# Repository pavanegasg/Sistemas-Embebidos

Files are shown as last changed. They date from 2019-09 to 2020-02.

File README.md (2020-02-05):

# EmPet
```
Maria Elisa Castro Fuñez 
Gabriel Martinez
Julian Molina 
Nicold Peña 
Juan Camilo Ramirez
Oscar Mauricio Segura 
Pedro Alejandro Vanegas 
```

### [Test de los 6 sombreros](https://github.com/pavanegasg/Sistemas-Embebidos/tree/master/Documentos/Test%20de%20los%206%20sombreros)

### Encontrando relaciones - escaleras preguntas

<p align="center">
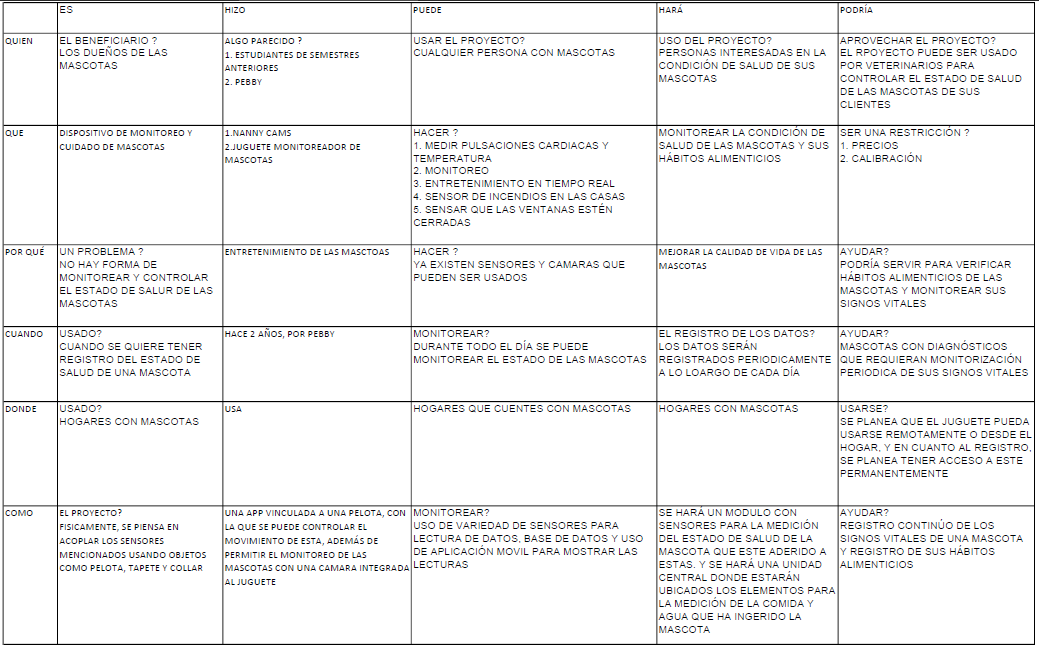
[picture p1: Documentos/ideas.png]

</p>

### Diagramas 

<p align="center">
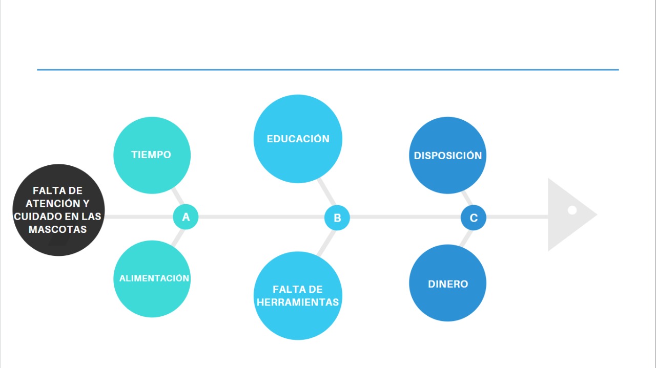
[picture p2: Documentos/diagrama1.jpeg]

</p>

<p align="center">
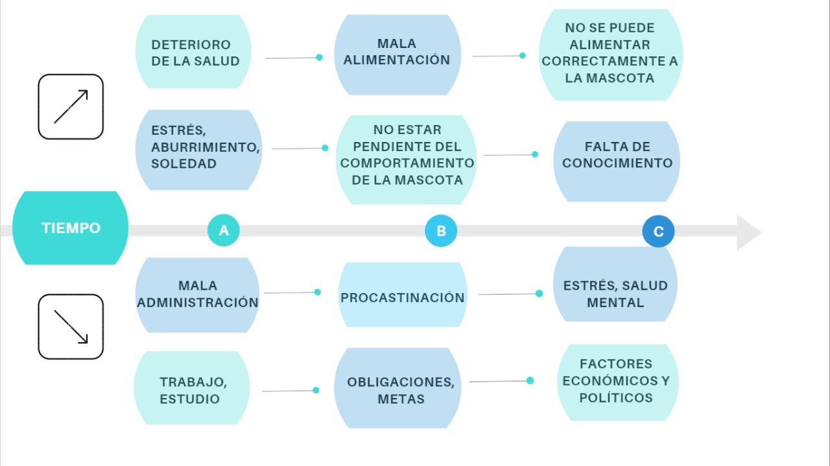
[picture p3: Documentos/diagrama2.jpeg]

</p>

### Problema 

<p align="center">
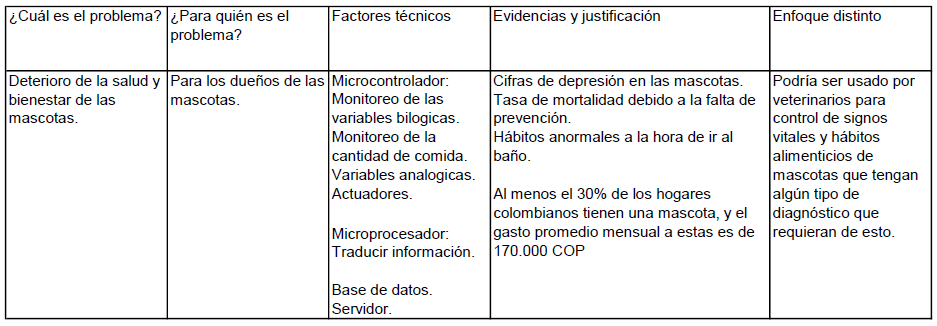
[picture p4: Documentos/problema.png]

</p>

### Asignación de tareas 

<p align="center">
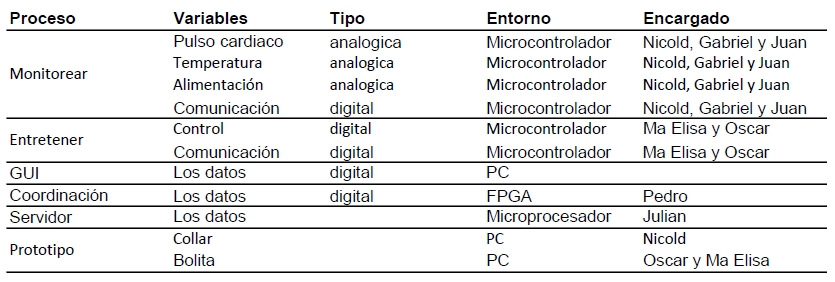
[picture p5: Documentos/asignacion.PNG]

</p>

### [Anteproyecto](https://github.com/pavanegasg/Sistemas-Embebidos/blob/master/Documentos/Anteproyecto_embebidos.pdf) 

### [Manuales](https://github.com/pavanegasg/Sistemas-Embebidos/tree/master/Manuales)

### [Códigos](https://github.com/pavanegasg/Sistemas-Embebidos/tree/master/Códigos)

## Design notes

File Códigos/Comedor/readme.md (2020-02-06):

**Nota:** Para la implementación de este codigo se hace necesario realizar una conexión por medio de UART con la FPGA, codigo desarrollado en la respectiva carpeta de dicha tarjeta.

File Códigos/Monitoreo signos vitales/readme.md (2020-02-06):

**Nota:** Este esta compuesto por dos códigos, uno para Arduino y uno para el modulo NodeMCU, los cuales trabajan en conjunto para enviar la información al servidor en la Raspberry.

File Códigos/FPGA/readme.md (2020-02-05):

El uso de la FPGA fue la conexión entre las [celdas de carga](https://github.com/pavanegasg/Sistemas-Embebidos/tree/master/Documentaci%C3%B3n/Sensores/HX711%20y%20celda%20de%20carga) y el [microprocesador](https://github.com/pavanegasg/Sistemas-Embebidos/tree/master/Manuales/Raspberry), además del procesamiento de la señal recibida del alimento y el agua de la mascota.

### 1. Conexión Microcontrolador-FPGA:

Esta conexión permite obtener los datos provenientes de las celdas de carga y llevarlos a la FPGA. La comunicación se hace en paralelo, donde se envían 8 bits correspondientes a cada dato, 16 en total para agua y comida.
   * Primera prueba:
   La primera prueba fue recibir datos de 4 bits para enviar esos mismos datos como salida y mostrar ese valor en los leds.
   
```verilog 
// rece.v

module rece( 
	input clk,                // Declaración de variables
	input [3:0] entero,
	output [3:0] tes,
	output [3:0] leds
	);

	assign leds[3] = RD ? !entero[3] : 1'b1;      //Asignación de leds
	assign leds[2] = RD ? !entero[2] : 1'b1;
	assign leds[1] = RD ? !entero[1] : 1'b1;
	assign leds[0] = RD ? !entero[0] : 1'b1;

	assign tes[3] = RD ? entero[3] : 1'b0;        //Asignación de salida 
	assign tes[2] = RD ? entero[2] : 1'b0;
	assign tes[1] = RD ? entero[1] : 1'b0;
	assign tes[0] = RD ? entero[0] : 1'b0;

	reg RD = 1;
	reg [1:0] state = START;
	parameter START=0, S1=1, STOP=2;

	reg divisor = 0;
	wire div;
	
	divisor divI(
		.clk(clk),
		.inicio(divisor),
		.CLKOUT(div)
		);

always @ (posedge clk)        //Máquina de estados para reiniciar el valor de la salida 
begin				
	case (state)
		
		START: begin	
			RD <= 1;
			state <= STOP;
		end

		STOP: begin 
			divisor <= 1;
			if(div) begin
			divisor <= 0; 
			RD <= 0;
			state <= START;
			end 
		end
	endcase
end 

endmodule   
```   
   * Segunda prueba:
     El segundo diseño consitió en recibir un número de 4 bits, y hacer que la salida fuera ese número menos el número recibido inmediatamente anterior. Adicionalmente, se muestra el valor de la salida en los leds de la tarjeta.
     
 ```verilog
 // ardn.v
 
 module rece( 
	input clk,
	input [3:0] dato,         //Definición de variables 
	output [3:0] salida,
	output [3:0] leds
	);

	assign salida = val;            // Asignación a la salida 
  reg [3:0] val;  
	assign leds = !salida;          // Asignación a los leds

	reg [1:0] state = START;
	parameter START=0, S1=1, STOP=2;

	reg divisor = 0;
	reg [3:0] valAnt = 0;
	wire div;
	
	divisor divI(           // Divisor para enviar el dato cada que se quiera
		.clk(clk),
		.inicio(divisor),
		.CLKOUT(div)
		);

always @ (posedge clk)     // Máquina de estados para almacenar valor anterior 
  begin				
	  case (state)
		
		START: begin	
			state <= STOP;
			valAnt <= dato;
      val <= 0;
		end

		STOP: begin           // Espera para enviar el siguiente dato
			divisor <= 1;
			if(div) begin
			divisor <= 0; 
			state <= START;
      val <= valAnt-dato;
			end 
		end

		default:
			state <= START;

	endcase
end 

endmodule    
```

### 2. Conexión FPGA-Microcontrolador
  
  La segunda parte consiste en enviar datos al microcontrolador por comunicación serial, para este caso se escogió UART, dada la fácil implementación. Los datos a enviar son los referentes a la diferencia de comida y agua actual con la medida un instante antes. 
  
  * Primera prueba:
 La primera prueba para esta sección fue la implementación de un puerto UART desde la FPGA, ya que a pesar de que la BlackIceMX cuenta con puertos seriales estos no están conectados directamente a la FPGA. El puerto implementado es una adaptación del puerto disponible en [open-fpga-verilog-tutorial](https://github.com/Obijuan/open-fpga-verilog-tutorial/wiki)

```verilog
//uart_tx.v

`default_nettype none
`include "baudgen.vh"

module uart_tx 
    #(
    parameter BAUD = `B115200
    )
    (
         input wire clk,        //-- Reloj del sistema (25MHz BlackIceMx)
         input wire rstn,       //-- Reset global
         input wire start,      //-- Activar a 1 para transmitir
         input wire [7:0] data, //-- Byte a transmitir
         output reg tx,         //-- Salida de datos serie
         output wire ready      //-- Transmisor listo / ocupado
       );

reg start_r; 
wire clk_baud;

//-- Bitcounter
reg [3:0] bitc;

//-- Datos registrados
reg [7:0] data_r;

//--------- Microordenes
wire load;    //-- Carga del registro de desplazamiento. Puesta a 0 del
              //-- contador de bits
wire baud_en; //-- Habilitar el generador de baudios para la transmision

//-------------------------------------
//-- RUTA DE DATOS
//-------------------------------------

//-- Registrar la entrada start

always @(posedge clk)
  start_r <= start;

always @(posedge clk)
  if (start == 1 && state == IDLE)
    data_r <= data;

//-- Registro de 10 bits para almacenar la trama a enviar:
//-- 1 bit start + 8 bits datos + 1 bit stop
reg [9:0] shifter;

//-- Cuando la microorden load es 1 se carga la trama
//-- con load 0 se desplaza a la derecha y se envia un bit, al
//-- activarse la señal de clk_baud que marca el tiempo de bit
//-- Se introducen 1s por la izquierda

always @(posedge clk)
  //-- Reset
  if (rstn == 0)
    shifter <= 10'b11_1111_1111;

  //-- Modo carga
  else if (load == 1)
    shifter <= {data_r,2'b01};

  //-- Modo desplazamiento
  else if (load == 0 && clk_baud == 1)
    shifter <= {1'b1, shifter[9:1]};

//-- Contador de bits enviados
//-- Con la microorden load (=1) se hace un reset del contador
//-- con load = 0 se realiza la cuenta de los bits, al activarse
//-- clk_baud, que indica el tiempo de bit

always @(posedge clk)
  if (load == 1)
    bitc <= 0;
  else if (load == 0 && clk_baud == 1)
    bitc <= bitc + 1;

//-- Sacar por tx el bit menos significativo del registros de desplazamiento
//-- ES UNA SALIDA REGISTRADA, puesto que tx se conecta a un bus sincrono
//-- y hay que evitar que salgan pulsos espureos (glitches)

always @(posedge clk)
  tx <= shifter[0];

//-- Divisor para obtener el reloj de transmision
baudgen #(.BAUD(BAUD))
  BAUD0 (
    .clk(clk),
    .clk_ena(baud_en),
    .clk_out(clk_baud)
  );

//------------------------------
//-- CONTROLADOR
//------------------------------

//-- Estados del automata finito del controlador
localparam IDLE  = 0;  //-- Estado de reposo
localparam START = 1;  //-- Comienzo de transmision
localparam TRANS = 2;  //-- Estado: transmitiendo dato

//-- Estados del autómata del controlador
reg [1:0] state;

//-- Transiciones entre los estados
always @(posedge clk)

  //-- Reset del automata. Al estado inicial
  if (rstn == 0)
    state <= IDLE;

  else
    //-- Transiciones a los siguientes estados
    case (state)

      //-- Estado de reposo. Se sale cuando la señal
      //-- de start se pone a 1
      IDLE: 
        if (start_r == 1) 
          state <= START;
        else 
          state <= IDLE;

      //-- Estado de comienzo. Prepararse para empezar
      //-- a transmitir. Duracion: 1 ciclo de reloj
      START:
        state <= TRANS;

      //-- Transmitiendo. Se esta en este estado hasta
      //-- que se hayan transmitido todos los bits pendientes
      TRANS:
        if (bitc == 11)
          state <= IDLE;
        else
          state <= TRANS;

      //-- Por defecto. NO USADO. Puesto para
      //-- cubrir todos los casos y que no se generen latches
      default:
        state <= IDLE;

    endcase

//-- Generacion de las microordenes
assign load = (state == START) ? 1 : 0;
assign baud_en = (state == IDLE) ? 0 : 1;

//-- Señal de salida. Esta a 1 cuando estamos en reposo (listos
//-- para transmitir). En caso contrario esta a 0
assign ready = (state == IDLE) ? 1 : 0;

endmodule
```

* Segunda prueba
  * Primera parte:
  La segunda prueba fue incorporar los datos provenientes de las celdas de carga y el modulo `uart_tx.v`. Primero se utilizó un valor fijo para la lectura de comida y agua.
  
```verilog  
//Top.v

`include "baudgen.vh"

	module Top(					// Declaración de variables
			input clk,			//	
			input [3:0] datoAgua,		
			input [3:0] datoPeso,
			output wire tx,
			output [1:0] stat
			);

	//Cables y registros para conexión de modulos 

	parameter BAUD = `B115200;			// Definición de tasa de baudios a usar en la comunicación serial

		reg resetUart = 0;			// Cables y registros para conexión de modulos
		reg startUart;

		wire [3:0] Comida;
		wire [3:0] Agua;

		wire [7:0] comidaFinal;
		wire [7:0] aguaFinal;
		assign comidaFinal = 8'b01111011;	// Valor fijo de agua y comida
		assign aguaFinal = 8'b01111101;
		reg [7:0] data;

		reg counter;				// Contador para máquina de estado	
		reg cena;
		wire readyUart;

		reg divStart = 0;
		wire divOut;

	//Instanciación modulos

	always @(posedge clk) begin			// Inicialización puerto serial 
		resetUart <= 1;
	end

	uart_tx #(.BAUD(BAUD)) Uart_txComida(		// Instanciación de modulos
			.clk(clk),
			.rstn(resetUart),
			.start(startUart),
			.data(data),
			.tx(tx),
			.ready(readyUart)
			);

	aguaMedida medicionAgua(
			.clk(clk),
			.agua(datoAgua),
			.salidaAgua(Agua)
			);

	pesoMedida medicionComida(
			.clk(clk),
			.peso(datoPeso),
			.salidaPeso(Comida)
			);

	always @*					// Contador
  		case (counter)
    		1'b0: data <= comidaFinal;
   			1'b1: data <= aguaFinal;
    		default: data <= ".";
  		endcase

  	always @(posedge clk)
		if (resetUart == 0)
    		counter = 0;
  		else if (cena)
    		counter = counter + 1;

	divisorTop divider(
		.clk(clk),
		.inicio(divStart),
		.CLKOUT(divOut)
		);

	// Máquina de estados para el control de las señales

	reg [1:0] state = START;
	parameter START=0, S1=1, S2=2, WAIT=3;
	assign stat = state;

	always @ (posedge clk)
	begin

		case(state)
			
			START: begin 				// Espera inicial
				divStart <= 1;
				if(divOut) begin 
					state <= S1;
					divStart <= 0;
				end
				else state <= START;
			end
		
			S1:  begin				// Transmisión de comida y agua 
				if(readyUart == 1) state <= S2;
				else state <= S1;
			end

			S2: begin				// Regresar a estado anterior cuando ya se haya transmitido 
				if(counter == 1) state <= WAIT; // comida. Pasar a estado siguiente cuando se hayan 
				else state <= S1;		// transmitido los dos valores
			end

			WAIT: begin				// Espera de 10 segundos
				divStart <= 1;
				if(divOut) begin 
					state <= START;
					divStart <= 0;
				end
				else state <= WAIT;
			end

			default: state <= START;

		endcase

	end

	always @*						// Asignación de microordenes

			case(state)
				START: begin
					startUart <= 0;
					cena <= 0;
				end

				S1: begin
					startUart <= 1;
					cena <= 0;
				end

				S2: begin  
					startUart <= 0;
					cena <= 1;
				end

				WAIT: begin
					startUart <= 0;
					cena <= 0;
				end

				default: begin 
					startUart <= 0;
					cena <= 0;
				end

			endcase

endmodule

```  

  * Segunda parte:
  La parte final fue cambiar el valor fijo de agua y comida y probar la transmisión.

 ### NOTA: Las versiones finales de los archivos y modulos mencionados están disponibles.

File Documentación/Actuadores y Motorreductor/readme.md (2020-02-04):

## Motorreductor
Un motorreductor es un reductor de velocidad con un motor directamente conectado. Entre sus ventajas se encuentra la compatibilidad con microcontroladores, Arduino, puede emplearse un cambio de velocidad con señales PWM y poseen un diseño compacto. Para esta apliacción se hizo uso de un motorreductor de 100rpm a 6V.

<p align="center">
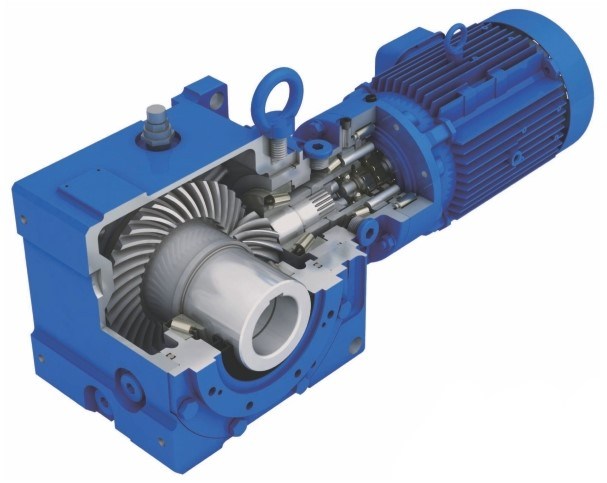
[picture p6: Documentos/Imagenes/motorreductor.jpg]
  
</p>

## Driver L298D
Un motor DC cambia el sentido de giro cuado invertimos los polos positivo y negativo en sus bordes,con ayuda del driver podemos realizar ese cambio de polaridad. El Driver puente H para motores L293D es un circuito integrado de cuatro canales diseñado para manejar cargas inductivas tal como lo es un motores DC hasta con una salida máxima de corriente de 600mA por canal en la configuración conocida como puente H. 

<p align="center">
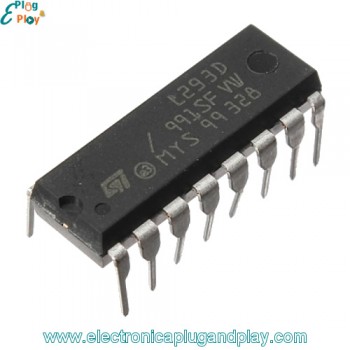
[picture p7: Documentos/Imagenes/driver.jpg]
  
</p>

## Señales PWM
El arduino puede generar señales PWM y así simular una tensión menor en voltios. Estas señales son las que permiten controlar el motor a través del puente H y controlar así la velocidad

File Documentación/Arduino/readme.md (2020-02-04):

## ¿Que es Arduino?

Esta es una compañía, proyecto y comunidad de hardware y software open-source que diseña y fabrica placas cuyo núcleo son microcontroladores, sus productos están licenciados bajo la LGPL o la GPL, lo cual permite la manufactura de placas Arduino por cualquier persona o entidad.
Esta es  ampliamente utilizada debido a su facilidad para la programación y la gran cantidad de librerías y sensores compatibles con esta, comercialmente hay gran variedad de placas Arduino, entre las que se destacaran el Arduino Nano y el Arduino Mega, las cuales serán empleadas en la realización de este proyecto.

## Prerrequisitos.

Para la utilización de estas placas hay gran variedad de programas mediante los cuales estas pueden ser programadas, entre ellas se destacan Visual Studio Code empleando la librería especifica para Arduino, Arduino Pro IDE (aun en beta) y Arduino IDE. Para la realización de este proyecto se empleo Arduino IDE, la cual puede ser descargada de manera gratuita en la pagina oficial de Arduino.

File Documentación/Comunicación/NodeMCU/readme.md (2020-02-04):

## ¿Qué es NodeMCU?
El NodeMCU es una plataforma IoT de código abierto basado en el chip ESP8266 (ESP-12E), siendo un entorno propicio para aplicaciones que requieran conectividad WiFi, de manera que es posible enviar y recibir datos e incluso controlas pines de entrada y salida de forma remota, de esta misma manera también es posible por medio de comunicación serial obtener los datos de los sensores recopilados por el arduino.

<p align="center">
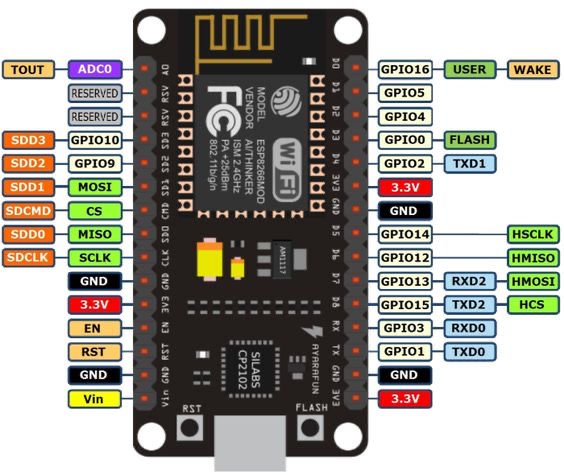
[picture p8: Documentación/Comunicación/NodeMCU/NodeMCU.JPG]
  
</p>

## Específicaciones técnicas

    -Procesador: ESP8266 @ 80MHz (3.3V) (ESP-12E)
    -4MB de memoria FLASH (32 MBit)
    -WiFi 802.11 b/g/n
    -Regulador 3.3V integrado (500mA)
    -Conversor USB-Serial CH340G / CH340G
    -Función Auto-reset 
    -9 pines GPIO con I2C y SPI
    -1 entrada analógica (1.0V max)
    -4 agujeros de montaje (3mm)
    -Pulsador de RESET
    -Entrada alimentación externa VIN (20V max)

## Prerrequisitos
Para realizar la respectiva utilización de este modulo, especialmente si se quiere utilizar un entorno conocido de programación se hace necesario instalar el pluggin del ESP8266 en el IDE de Arduino con el fin de evitar montar un entorno de desarrollo para utilizar la SDK de Espressif y posteriormente de la misma forma en que se procede en Arduino instalar la libreria PubSubClient, con el fin de convertir dicho módulo en el cliente del servidor ubicado en la Raspberry Pi.

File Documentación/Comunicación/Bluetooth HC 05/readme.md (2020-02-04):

## Bluetooth HC 05
El módulo Bluetooth HC-05 permite conectar el proyecto con Arduino nano a un celular de manera inalámbrica (Bluetooth). La comunicación
Bluetooth se da entre dos tipos de dispositivos: Maestro y Esclavo.  El módulo Bluetooth HC-05 viene configurado de fábrica para trabajar 
como esclavo, es decir, preparado para escuchar peticiones de conexión; lo cual es conveniente en este caso ya que el celular se comportará
como maestro.

 <p align="center">
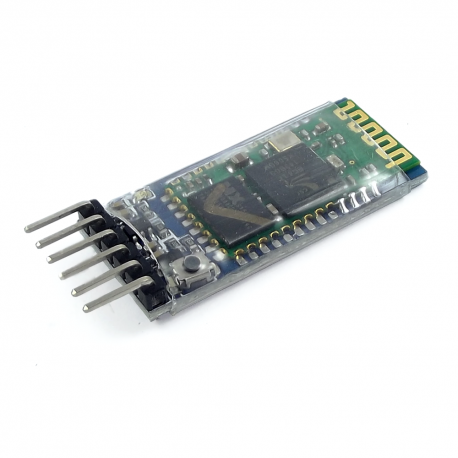
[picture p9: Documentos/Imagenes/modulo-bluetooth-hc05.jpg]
hover text
  
</p>
Este módulo cumple con las especificaciones del estándar Bluetooth 2.0 que es perfectamente compatible con celulares o smartphones Android, 
más no con los Iphone. 

## Especificaciones Técnicas

     -Voltaje de operación: 3.6V - 6V DC
     -Consumo corriente: 50mA
     -Alcance 10 metros
     -Interface comunicación: Serial TTL
     -Baudrate por defecto: 9600.
     -Temperatura de trabajo: -20C a +75C
     -Compatible con Android

## Estados del módulo 

 **Estado conectado**
 
 - Entra a este estado una vez se ha alimentao el módulo no se ha establecido una conexión bluetooth con ningún otro dispositivo.
 - EL LED del módulo en este estado parpadea rápidamente
 
 **Estado desconectado**
 
 - Entra a este estado cuando se establece una conexión con otro dispositivo bluetooth.
 - El LED hace un doble parpadeo.
 
 ## Conexión con el celular
 
El celular como se había mencionado anteriormente, funciona en este caso como maestro. La conexión se realiza mediante la app creada con el SDK de código abierto, Ionic. La cual posee un complemente llamado **Bluetooth Serial**, facilitando la comunicación. 

    //Instalación del complemento
    $ ionic cordova plugin add cordova-plugin-bluetooth-serial
    $ npm install --save @ionic-native/bluetooth-serial

Posteriormente se definen en el archivo **.ts** las funciones que por medio de la dirección permiten realizar la conexión entre la app y el dispositivo (HC 05). 
  
    -CheckBluetoothEnable()
    -ListPairedDevices()
    -SelectDevice()
    -connect(address)
    -deviceConnect()
    -SendData()
    -ShowError()
    
 Se define la función para escribir 
 
    // Para escribir una función
     this.bluetoothSerial.write('hello world').then(success, failure)
     
Finalmente en el **.html** se llama la función con agregando **class " "** en cada botón para que envíe vía bluetooth el dato al HC05 y sea leído por el Arduino nano.

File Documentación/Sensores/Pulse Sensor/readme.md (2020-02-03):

## ¿Qué es Pulse Sensor?

Pulse sensor es un sensor diseñado por Joel Murphy y Yury Gitman, el cual permite medir la absorción de la luz por la piel, mediante este simple principio y conociendo el hecho de que el coeficiente de absorción de la luz en la piel varia en función de la irrigación sanguínea, se puede obtener fácilmente el pulso de un ser vivo.

## Prerrequisitos

Para la utilización de este sensor se empleo la libreria _PulseSensor Playground_ la cual se puede descargar en el IDE de Arduino.

## Pruebas preliminares

Esta prueba se realizo con la finalidad de obtener una medición de la señal análoga recibida por el Arduino proveniente del sensor, la cual como se puede observar en la siguiente imagen, corresponde a la grafica del ritmo cardiaco del sujeto de prueba. 

<p align="center">
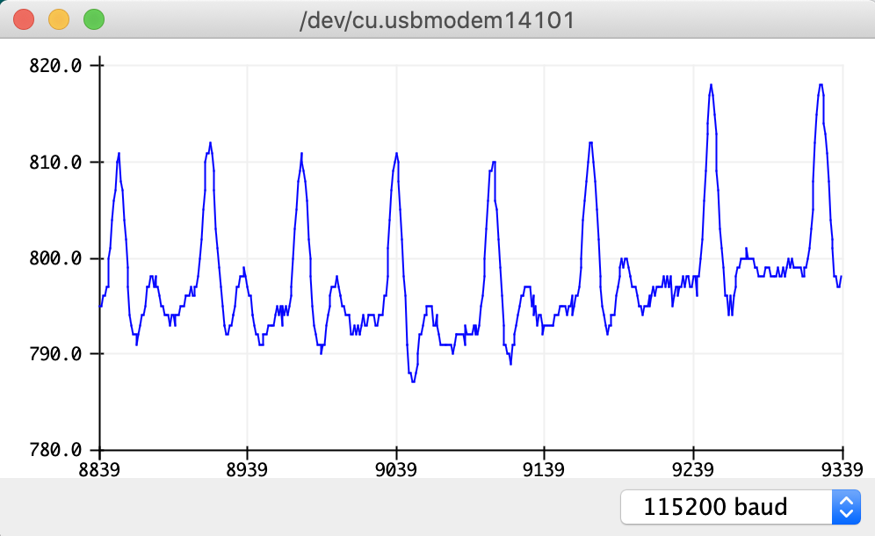
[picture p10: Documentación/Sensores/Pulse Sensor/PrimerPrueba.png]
  
</p>

## Obtención del BPM en humanos 

Para la obtención de los latidos por minuto se hizo uso de la información obtenida la prueba preliminar, con esta se determino que un latido sucedía cada vez que la señal proveniente del sensor superaba un umbral, con esta información se empleo un programa que detecta el tiempo que transcurre entre latidos y con el inverso de este tiempo se obtiene la frecuencia cardiaca de la persona.

Para poder definir este umbral es necesario calibrar el sensor, esta se realiza observando el valor proveniente del sensor, en el caso del sujeto de prueba empleado se encontró que este es de 520.

<p align="center">
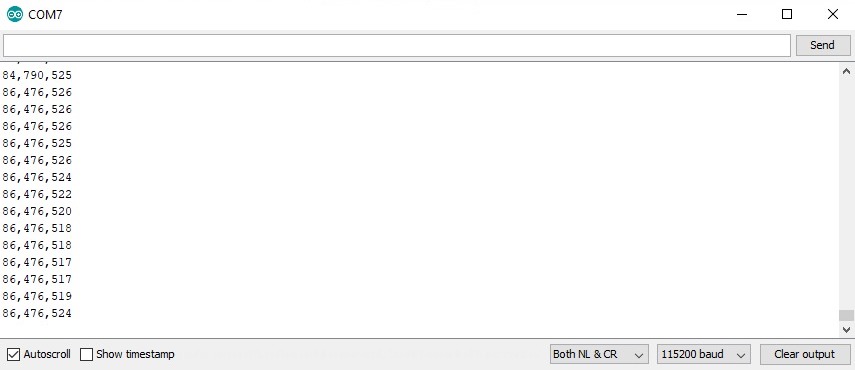
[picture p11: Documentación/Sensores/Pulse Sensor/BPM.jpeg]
  
</p>

En la imagen anterior se presenta lo obtenido por el programa, donde el primer valor presentado es la frecuencia cardiaca (en latidos por minuto), y el ultimo es el valor entregado por el sensor.

## Obtención del BPM en perros

Para la obtención de esta se emplea el mismo programa que en la sección anterior, sin embargo de debe realizar una nueva calibración, en este caso el sujeto de prueba fue un labrador dorado adulto, el sensor se ubico en la ingle del perro debido a la poca cantidad de pelo y la presencia de venas y arterias cercanas a la piel, en este caso el valor de calibración fue de 507.

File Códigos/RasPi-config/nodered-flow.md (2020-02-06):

[{"id":"47478305.0319c4","type":"tab","label":"Flow 2","disabled":false,"info":""},{"id":"72740e37.67a17","type":"mysql","z":"47478305.0319c4","mydb":"a0fbdf07.eeae4","name":"","x":670,"y":60,"wires":[["ad2dbcd0.e6513"]]},{"id":"ad2dbcd0.e6513","type":"debug","z":"47478305.0319c4","name":"result_MYSQL","active":true,"tosidebar":true,"console":false,"tostatus":false,"complete":"payload","targetType":"msg","x":880,"y":60,"wires":[]},{"id":"5fe88209.a46e04","type":"function","z":"47478305.0319c4","name":"function_outMYSQL","func":"var date = new Date();\nvar dateS = date.getFullYear() + \"-\" + (date.getMonth()+1) + \"-\" + date.getDate() + \" \" + \ndate.getHours() + \":\" + date.getMinutes() + \":\" + date.getSeconds();\n\nvar out = \"INSERT INTO Sensores (Timestamp,Tema,Valor)\"\nout = out + \" VALUES ('\" + dateS + \"','\"\nout = out + msg.topic.substring(8,14) + \"','\" + msg.payload + \"');\"\n\nmsg.topic = out;\n//msg.payload = date.toISOString();\nreturn msg;","outputs":1,"noerr":0,"x":480,"y":60,"wires":[["72740e37.67a17","4092ded0.76888"]]},{"id":"47d6244e.e12bc4","type":"mqtt in","z":"47478305.0319c4","name":"","topic":"/sensor/temp","qos":"2","datatype":"auto","broker":"b8060e50.fd718","x":170,"y":60,"wires":[["5fe88209.a46e04","fe08fabe.a699b8"]]},{"id":"50b7e72d.f6ad6","type":"debug","z":"47478305.0319c4","name":"MQTT_out","active":true,"tosidebar":true,"console":false,"tostatus":false,"complete":"payload","targetType":"msg","x":870,"y":180,"wires":[]},{"id":"4092ded0.76888","type":"debug","z":"47478305.0319c4","name":"outFunction","active":true,"tosidebar":true,"console":false,"tostatus":false,"complete":"payload","targetType":"msg","x":690,"y":120,"wires":[]},{"id":"fe08fabe.a699b8","type":"function","z":"47478305.0319c4","name":"function_cutTopic","func":"msg.payload = msg.topic.substring(8,14);\nreturn msg;","outputs":1,"noerr":0,"x":470,"y":180,"wires":[["50b7e72d.f6ad6"]]},{"id":"7860ca9b.3d0ea4","type":"http in","z":"47478305.0319c4","name":"datos","url":"/datos","method":"get","upload":false,"swaggerDoc":"","x":180,"y":360,"wires":[["173f1283.56ca75","1d2e217a.2127e7"]]},{"id":"1d2e217a.2127e7","type":"function","z":"47478305.0319c4","name":"","func":"var out = \"SELECT * from Sensores ;\";\n\nmsg.topic = out;\n\nreturn msg;","outputs":1,"noerr":0,"x":370,"y":360,"wires":[["e8d101f4.0d70d"]]},{"id":"173f1283.56ca75","type":"debug","z":"47478305.0319c4","name":"","active":true,"tosidebar":true,"console":false,"tostatus":false,"complete":"false","x":390,"y":280,"wires":[]},{"id":"25584753.cec918","type":"http response","z":"47478305.0319c4","name":"ok","statusCode":"200","headers":{},"x":730,"y":360,"wires":[]},{"id":"659066c4.30bdf8","type":"debug","z":"47478305.0319c4","name":"","active":true,"tosidebar":true,"console":false,"tostatus":false,"complete":"false","x":700,"y":280,"wires":[]},{"id":"59923bbc.c90f1c","type":"serial in","z":"47478305.0319c4","d":true,"name":"","serial":"","x":290,"y":460,"wires":[["9205f458.bfec18"]]},{"id":"9205f458.bfec18","type":"debug","z":"47478305.0319c4","d":true,"name":"","active":true,"tosidebar":true,"console":false,"tostatus":false,"complete":"payload","targetType":"msg","x":460,"y":460,"wires":[]},{"id":"871113a7.a321a","type":"mqtt in","z":"47478305.0319c4","name":"","topic":"/sensor/pulso","qos":"2","datatype":"auto","broker":"b8060e50.fd718","x":170,"y":140,"wires":[["5fe88209.a46e04","fe08fabe.a699b8"]]},{"id":"e8d101f4.0d70d","type":"mysql","z":"47478305.0319c4","mydb":"a0fbdf07.eeae4","name":"","x":530,"y":360,"wires":[["25584753.cec918","659066c4.30bdf8"]]},{"id":"5da7083b.4d9ad8","type":"mqtt in","z":"47478305.0319c4","name":"","topic":"/test/test1","qos":"2","datatype":"auto","broker":"b8060e50.fd718","x":235,"y":681,"wires":[["66190b3b.bdb6ec","b42867c2.7bdf08"]]},{"id":"66190b3b.bdb6ec","type":"debug","z":"47478305.0319c4","name":"","active":true,"tosidebar":true,"console":false,"tostatus":false,"complete":"false","x":485,"y":681,"wires":[]},{"id":"b42867c2.7bdf08","type":"mqtt out","z":"47478305.0319c4","name":"","topic":"/test/test2","qos":"2","retain":"","broker":"b8060e50.fd718","x":485,"y":841,"wires":[]},{"id":"fb232d6d.9a9b98","type":"inject","z":"47478305.0319c4","name":"","topic":"","payload":"0","payloadType":"str","repeat":"","crontab":"","once":false,"onceDelay":0.1,"x":235,"y":801,"wires":[["b42867c2.7bdf08"]]},{"id":"b8ef94ef.64cd2","type":"inject","z":"47478305.0319c4","name":"","topic":"","payload":"1","payloadType":"str","repeat":"","crontab":"","once":false,"onceDelay":0.1,"x":230,"y":880,"wires":[["b42867c2.7bdf08"]]},{"id":"1b96c85c.99e69","type":"firebase query","z":"47478305.0319c4","name":"","firebaselogin":"empet-ae1d1","firebasepath":"Estado","child":"","x":450,"y":540,"wires":[["57adb6ba.dd9498"]]},{"id":"9dfbf9e0.cddb68","type":"inject","z":"47478305.0319c4","name":"","topic":"","payload":"","payloadType":"date","repeat":"","crontab":"","once":false,"onceDelay":0.1,"x":300,"y":540,"wires":[["1b96c85c.99e69"]]},{"id":"57adb6ba.dd9498","type":"debug","z":"47478305.0319c4","name":"","active":true,"tosidebar":true,"console":false,"tostatus":false,"complete":"false","x":640,"y":540,"wires":[]},{"id":"a0fbdf07.eeae4","type":"MySQLdatabase","z":"47478305.0319c4","host":"localhost","port":"3306","db":"EmPet","tz":""},{"id":"b8060e50.fd718","type":"mqtt-broker","z":"47478305.0319c4","name":"EmPetMQTT","broker":"10.42.0.29","port":"1883","clientid":"","usetls":false,"compatmode":false,"keepalive":"60","cleansession":true,"birthTopic":"","birthQos":"0","birthPayload":"","closeTopic":"","closeQos":"0","closePayload":"","willTopic":"","willQos":"0","willPayload":""}]

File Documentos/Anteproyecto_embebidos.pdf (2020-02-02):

PRIMERA ENTREGA PROYECTO, SISTEMAS EMBEBIDOS, BOGOTA D.C., COLOMBIA, 2 DE FEBRERO DE 2020 | 1 ´

# Anteproyecto: EmPet

Maria E. Castro F.¹

, Gabriel F. Martinez E. 2
, Julian F. Molina G. ´

3
, Nicold M. Pena C. ˜

4
,
Oscar M. Segura P. 5
, Juan C. Ramirez G. 6
, Pedro A. Vanegas G. 7

{

1 mecastrof, 2 gfmartineze, 3 jufmolinagr, 4 nmpenac, 5 omsegurap,

6

jucramirezgo, 7 pavanegasg }@unal.edu.co

I. INTRODUCCION´

El amor de las personas por sus mascotas ha llevado al crecimiento de un mercado lleno de dispositivos que permiten medir variables vitales de nuestras mascotas, monitorizar sus habitos alimenticios o hasta jugar con ellos, sin embargo, no ´ se ha presentado un producto unificado que permita realizar todas estas acciones, aquí es donde entra EmPet como una alternativa que permitira monitorizar el estado de salud y ´ jugar con nuestras mascotas mientras estamos fuera de casa.
A continuacion, se detallar ´ | an los objetivos de este proyecto y ´
las diversas tareas que llevaran a al desarrollo de un prototipo ´ funcional, junto con la presentacion de otros dispositivos que ´ sirvieron de inspiracion para el desarrollo de este proyecto. ´

II. DEFINICION DEL PROBLEMA ´

El problema que se encontro fue el deterioro en su salud ´ y bienestar de las mascotas a causa de la falta de atencion´ prestada.

III. ANTECEDENTES

III-A. Inuphaty

Inuphaty es uno de los diferentes dispositivos que permiten medir el ritmo cardiaco de los perros. Consiste en un arnes que ´ permite al dueno de la mascota conocer su estado de salud. ˜ Este dispositivo hace enfasis en los canes, sin embargo no ´ descarta otras especies. Por medio de distintos colores muestra
como se est ´ | a sintiendo el animal; As ´ | í, un color verde muestra
un estado de relajacion, color rojo muestra excitaci ´ | on, blanco ´
muestra interes, violeta indica estr ´ | es y multicolor demuestra ´
alegría.

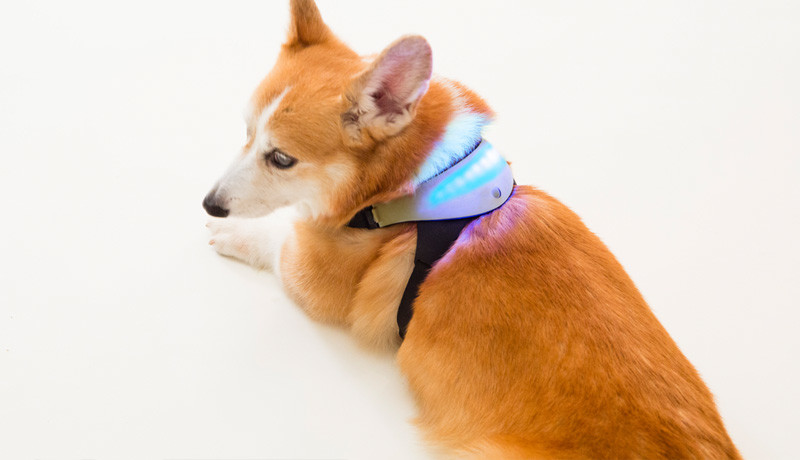
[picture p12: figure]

Figura 1. Dispositivo de monitoreo Inuphaty.[1]

III-B. PetPace
Es un dispositivo disponible para perros y gatos que funcio-na como un monitor de salud completo. Este collar de reducido tamano realiza el seguimiento del pulso, temperatura corpo- ˜
ral, respiracion, calor ´ | ías quemadas, actividad física e incluso
postura. Cuando se presenta cualquier cambio considerable, el dispositivo genera una alerta y notifica al usuario por medio de una aplicacion. ´

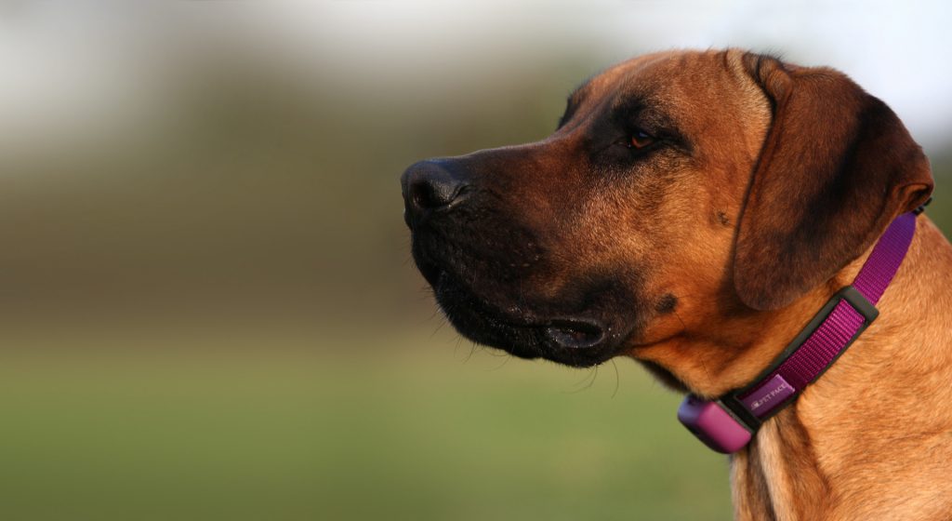
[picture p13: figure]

Figura 2. Dispositivo de monitoreo PetPace.[1]

III-C. Fitbark
Se trata de un monitor de actividad que permite registrar qué tanto ejercicio realizan los perros. Se transporta en un collar y puede ser conectado por medio de WiFi a su base de carga.
Por medio de la interaccion con una aplicaci ´ | on para celular, ´
este dispositivo proporciona al usuario informacion sobre la ´ actividad física y los niveles de descanso de su mascota, permitiendo comparar estos datos con los obtenidos por otros perros. Tambien proporciona alertas en caso de que se requiera ´ una mayor o menor actividad de la mascota.

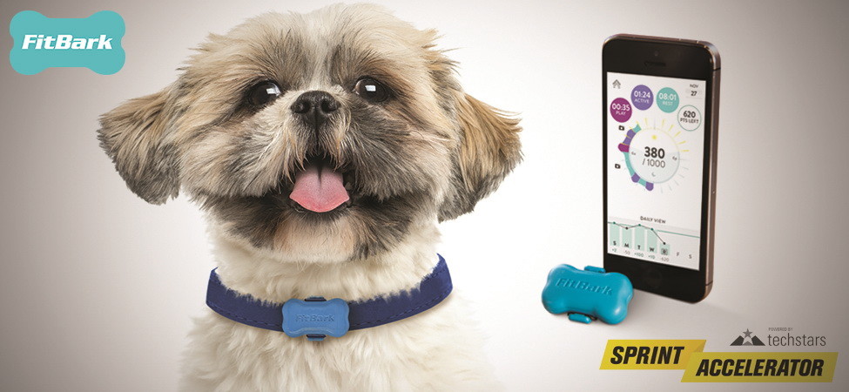
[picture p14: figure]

Figura 3. Dispositivo de monitoreo Fitbark.[1]

IV. JUSTIFICACION´

En Colombia cerca de cuatro millones de hogares poseen mascotas, estos animales de compan˜ía se han convertido en un miembro mas de la familia, por lo que su salud y bienestar es ´

PRIMERA ENTREGA PROYECTO, SISTEMAS EMBEBIDOS, BOGOTA D.C., COLOMBIA, 2 DE FEBRERO DE 2020 | 2 ´

primordial en la armonía de los hogares. Si bien las mascotas
son de vital importancia para sus duenos, las responsabilidades ˜
academicas, laborales y sociales de los mismos, hacen que ´ dichos animales pasen varias horas al día solos. Por lo anterior, se hace necesario incluir herramientas que ayuden a velar por la integridad de las mascotas cuando su dueno o cuidador no ˜ puede estar con ellas, de esta manera nace EmPet.
V. OBJETIVOS

V-A. Objetivo general
Construir un prototipo funcional de un dispositivo que permita a un usuario interactuar y monitorear el comportamiento de sus mascotas, específicamente perros.

V-B. Objetivos específicos
Disenar e implementar un sistema que permita medir el ˜ ritmo cardíaco y la temperatura corporal de un perro. Disenar e implementar un juguete para la mascota el cual ˜ el usuario pueda activar de manera remota.
Disenar e implementar un sistema que lleve registro de ˜ la cantidad de comida que la mascota ingiere.
Crear una base de datos en la que se pueda comparar los datos obtenidos y con esto informar adecuadamente al usuario del estado de su mascota.
Disenar y crear una aplicaci ˜ | on en la que el usuario pueda ´
ver de manera simplificada el estado de su mascota.

VI. DEFINICION´ TAREAS

A continuacion, se definir ´ | an las tareas que ser ´ | an necesarias ´
completar para llegar a un prototipo funcional del proyecto.
1. Caracterizacion y adquisici ´ | on de datos con sensores ´
De esta tarea se encargara Gabriel F. Mart ´ | ínez, Nicold
M. Pena y Juan C. Ram ˜ | | írez, esta tarea consiste en tres
subsecciones las cuales son:
Sensor de pulso cardiaco
Para la realizacion de este proyecto se eligi ´ | o un sensor ´
de pulso llamado Amped desarrollado por la empresa
Adafuit, este entrega una senal an ˜ | aloga que muestra el ´
cambio en la irrigacion sangu ´ | ínea, lo cual representa
el pulso.
Sensor de temperatura
Para la medicion de la temperatura se emplear ´ | a un ´
sensor LM35 el cual esta calibrado para entregar una
senal DC que sigue la siguiente relaci ˜ | on: ´
| T =

Vo
10mV
Donde T es la temperatura en grados centígrados y Vo es el voltaje de salida del transistor, este puede medir valores mayores a −55◦C y menores a 105◦C, este ha sido trabajado anteriormente por el grupo encargado de su caracterizacion en varios proyectos. ´
Balanza electronica ´
Para la medicion del peso de la comida del animal ´ se empleara una celda de carga de 5 kg y un modulo ´ HX711 el cual entrega un valor analogo sencillo de ´ tratar.
2. Caracterizacion y env ´ | ío de datos mediante modulo ´
Wifi
De esta tarea se encargara Gabriel F. Mart ´ | ínez, Nicold
M. Pena y Juan C. Ram ˜ | írez, esta consiste en acoplar
un modulo Wifi, espec ´ | íficamente el ESP8266 (version´
ESP-01), a un Arduino y mediante este enviar los datos recolectados con los sensores hacia la Raspberry Pi.
3. Diseno de dispositivo para juego remoto ˜
Esta tarea consiste en elegir los motores, puentes H y formas de alimentacion adecuados, con el fin de encontrar ´ los componentes de mayor eficiencia y menor tamanõ
para la implementacion de una pelota que interact ´ | ue con ´
la mascota y sea encendida de manera remota. De esto tarea se encargara Mar ´ ía E. Castro y Oscar M. Segura.
4. Creacion del servidor en la Raspberry Pi ´
Consiste en la creacion de un servidor que permita ´ conectar los diferentes prototipos a la Raspberry Pi, cuyo encargando es Julian F. Molina, con el fin de interactuar con los demas dispositivos tal como se muestra a conti- ´ nuacion: ´

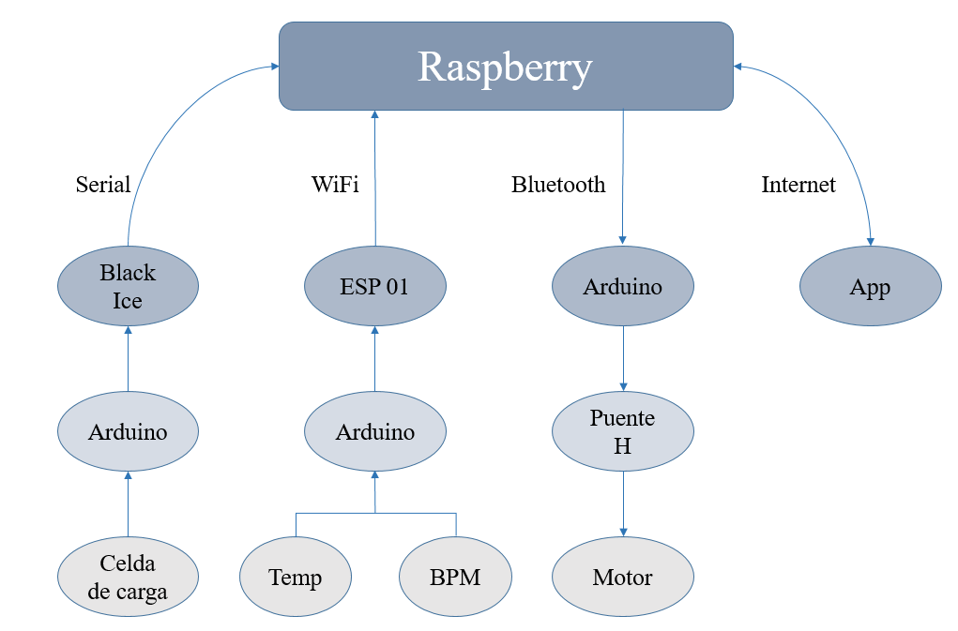
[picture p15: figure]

Figura 4. Diagrama de conexion de los diferentes dispositivos. ´

5. Monitorizacion de la cantidad de alimento ingerido. ´
De esta tarea se encargara Gabriel F. Mart ´ | ínez, Nicold
M. Pena, Juan C. Ram ˜ | írez y Pedro A. Vanegas, esta
consiste en tomar los datos recolectados por la balanza y enviarlos a la Black Ice para generar un registro sobre la cantidad de alimento que la mascota esta consumiendo ´ y posteriormento ser enviado a la Raspberry Pi para ser almacenados.
6. Diseno del collar, juguete y taz ˜ | on´
Esta tarea se subdivide en tres, las cuales son:
Diseno del collar ˜
Esta tarea sera realizada por Nicold M. Pe ´ | na. ˜
Diseno del juguete ˜
Esta tarea sera realizada por Maria E. Castro y Oscar ´
M. Segura.
Diseno del taz ˜ | on´
Esta tarea sera realizada por Gabriel F. Martinez. ´
7. Creacion de base de datos y gesti ´ | on de alertas ´
De esta tarea se encargara todo el grupo, esta consiste en ´ la creacion de una base de datos en la Raspberry Pi, en la ´

PRIMERA ENTREGA PROYECTO, SISTEMAS EMBEBIDOS, BOGOTA D.C., COLOMBIA, 2 DE FEBRERO DE 2020 | 3 ´

cual se almacenaran los datos enviados por los diferentes ´
perifericos, adem ´ | as de coordinar algunas se ´ | nales de alerta ˜
al dueno de la mascota en caso de una emergencia y ˜ comunicar a este con el juguete de la tarea 3.
8. Creacion de la aplicaci ´ | on´
De esta tarea se encargara nuevamente todo el grupo
y se realizara en paralelo a la creaci ´ | on de la base de ´
datos, esta consiste en la creacion de una aplicaci ´ | on que ´
permita al usuario visualizar los signos vitales de su mascota, monitorear la cantidad de alimento consumido, encender o apagar el juguete de forma remota y mostrar una pequena enciclopedia sobre temas referentes a la ˜ salud de las mascotas, por lo cual se plantea el mapa
de navegacion presentado en la figura ´ | 5.

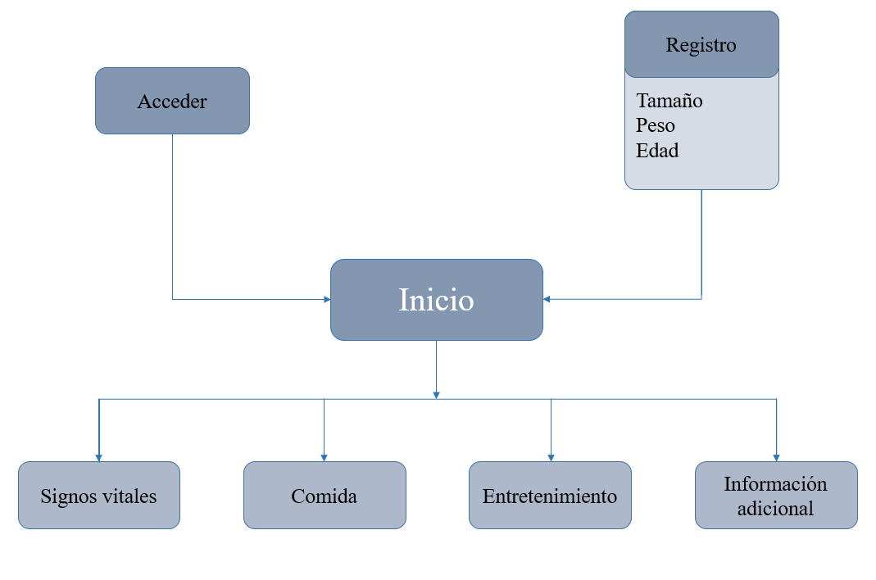
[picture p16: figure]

Figura 5. Mapa de navegacion para la aplicaci ´ | on. ´

VII. AVANCES
1. Caracterizacion y adquisici ´ | on de datos con sensores ´
Sensor pulso cardiaco
Este ya ha sido trabajado y se ha logrado detectar la senal exitosamente en nuestros dedos y en los ˜
lobulos de nuestras orejas, sin embargo todav ´ | ía no
ha sido probado en un perro. De manera que es posible representar los datos obtenidos en tiempo real de acuerdo a su respectiva medicion, donde es posible ´
observar la obtencion de los mismos tanto gr ´ | afica como ´
analíticamente, mostrando un promedio de los latidos por minuto.
Sensor de temperatura
Por su parte para el sensor de temperatura se hizo uso del LM35 debido a su relativa facilidad para realizar
la calibracion y en especial debido a su tama ´ | no. En ˜
este caso ya se tiene caracterizado en su totalidad e igualmente ha sido probado con diferentes fuentes de calor conocidas, sin embargo, hace falta realizar la respectiva medida con el animal en cuestion, debido ´ a que la medicion debe hacerse en una zona poco ´ accesible.
Balanza electronica ´
En este caso ser requirio inicialmente realizar una ´ prueba del montaje de la celda de carga, con el fin de optimizar sus mediciones, incluyendo una base y un soporte sobre el cual medir, que posteriormente
se mejorara para entregar un prototipo m ´ | as acorde ´
con el producto final que se desea a los clientes, una vez desarrolladas dichas pruebas se procedio a ´
ejecutar la caracterizacion y calibraci ´ | on de la balanza ´
con pesos conocidos y en específico con una unidad bajo prueba que nos permite recalibrar la celda de carga con respecto a las condiciones del medio, tales como la temperatura, que pueden afectar la medicion. ´
2. Diseno de dispositivo para juego remoto ˜
Seleccion de componentes ´
Se selecciono como medio de alimentaci ´ | on una bater ´ | ía
de celular de 3.7V debido a que proporciona la energía suficiente para el proposito del dispositivo. Se selec- ´ cionaron tambien motor-reductores de referencia N20 ´ debido a su tamano reducido y la velocidad que propor- ˜ cionan con la alimentacion escogida. De igual forma, ´ se decidio hacer uso de un puente H de referencia ´ L239D, nuevamente elegido por su reducido tamanõ y especificaciones suficientes al momento de controlar el accionamiento e los motores a utilizar. Finalmente, se hizo uso de un modulo bluetooth HC-05 y un ´ arduino nano, por medio de los cuales se controlará
el dispositivo y su conexion con la aplicaci ´ | on. ´
Diseno de la cubierta exterior del juguete ˜
Se realizo un dise ´ | no en el software OpenScad que ˜
consiste en media esfera con un cilindro en el medio, el cual servira de soporte para los componentes que ´
estaran en el interior de la esfera y los proteger ´ | a de ´
impactos, ademas de permitir el movimiento como tal ´ del dispositivo. Se mandaron a imprimir dos piezas
identicas a la que se muestra a continuaci ´ | on. ´

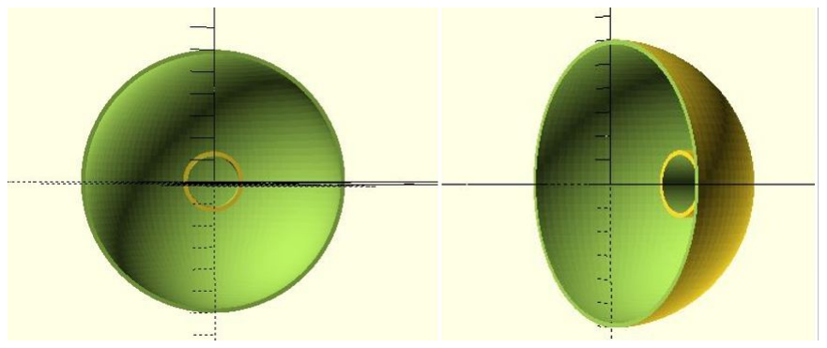
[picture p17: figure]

Figura 6. Prototipo del juguete.

3. Monitorizacion de la cantidad de alimentos ingeridos ´ Comunicacion Arduino-BlackIce Mx: A este punto se ´ ha enviado la informacion medida por la celda de carga ´ desde el Arduino a la BlackIce Mx usando transferencia de datos en paralelo.
4. Base de datos
Para la realizacion de la base de datos se tom ´ | o como ´
fuente la asociacion para la prevenci ´ | on de obesidad en ´
las mascotas (PETMD), mostrado en un esquema en la
Figura 7. En los cuales se tendra en cuenta, a trav ´ | es´
de datos ingresados a la aplicacion m ´ | ovil, el peso de la ´
mascota, el tamano y la actividad diaria para determinar ˜
un límite inferior y superior el cual notifique una se ´ | nal ˜

PRIMERA ENTREGA PROYECTO, SISTEMAS EMBEBIDOS, BOGOTA D.C., COLOMBIA, 2 DE FEBRERO DE 2020 | 4 ´

de alerta al ususaio en caso de no encontrarse en este
intervalo.

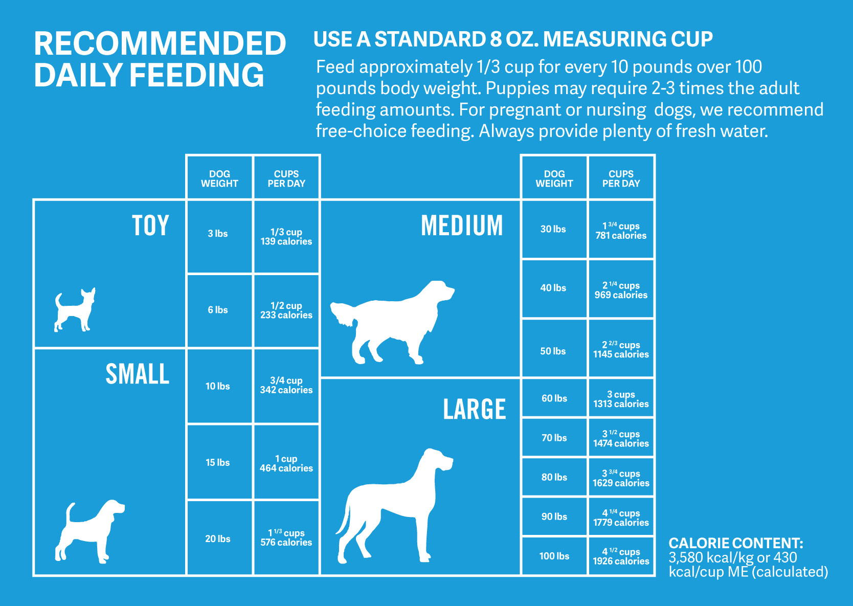
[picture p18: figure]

Figura 7. Esquema de la alimentacion diaria recomendada para caninos. [ ´ | 3]

Para la medicion del pulso cardiaco se toma en cuenta ´
el libro de Examen y diagnostico cl ´ | ínico en veterinaria,
del autor Otto M. Radostits; en donde expone los datos mostrados en la siguiente tabla:
Animal | Intervalo
Cachorros de Perro | 110-220
Perro adulto, raza pequenã | 80-180
Perro adulto, raza mediana | 70-160
Perro adulto, raza grande | 60-140
TABLA I
FRECUENCIA CARDIACA DE LOS PERROS. [2]

VII-A. Resumen de avances.

Tarea | | Porcentaje de avance
Caracterizacion y adquisici ´ | on de datos con sensores | 95 ´
Caracterizacion y env ´ | ío de datos mediante modulo Wifi | 10
Diseno de dispositivo para juego remoto | 100 ˜
Creacion del servidor Raspberry Pi | 90 ´
Monitorizacion de la cantidad de alimento ingerido | 40 ´
Diseno de collar, juguete y taz ˜ | on | 60 ´
Creacion de base de datos y gesti ´ | on de alertas | 10 ´
Creacion de la aplicaci ´ | on | 10 ´

VIII. CRONOGRAMA

### 7 de Octubre

En estas semanas se finalizara la tarea numero 1 y 4, ´ adicionalmente se trabajara en la tarea 3. ´

### 21 de Octubre al 3 de Noviembre

En estas semanas se finalizara la tarea 3. ´

### 27 de Enero al 2 de Febrero

En esta semana se finalizaran todas las tareas propuestas. ´

### 3 de Febrero

Entrega relatoria en git hub.

### 5 de Febrero

Entrega codigos fuente y dise ´ | nos. ˜

### 10 a 12 de febrero

Prototipo funcional y modelo de negocio.

IX. PRESUPUESTO
A continuacion, se enlistar ´ | a los elementos de hardware ´
que ha sido y sera necesario adquirir para la realizaci ´ | on del ´
proyecto, junto con el dinero que se estima se gastara en la ´
adquisicion de materiales necesarios para la realizaci ´ | on del ´
prototipo.
Finalmente se establecio una reserva de ochenta mil pesos ´ para poder adquirir algun elemento no previsto o solucionar ´ un contratiempo.
Cantidad | Item | Valor (COP)
Hardware
1 | Sensor de pulso | 22.200
1 | Sensor de temperatura | 4.000
1 | Balanza electronica | 25.850 ´
2 | Modulo Wifi | 24.700
2 | Motor | 40.000
1 | Puente H | 9.000
2 | Arduino Nano | 28.850
2 | Batería 9V | 10.000
2 | Adaptador Batería | 2.000
1 | Raspberry Pi | 159.000
1 | Black Ice | 246.000
Otros
1 | Collar para perro/gato | 30.000
1 | Tazon para comida | 24.000 ´
| Elementos para construccion´
| del prototipo | 40.000
| Reserva Imprevistos | 70.000
TOTAL | | 735.600

2
34
X. ANEXO
1. Eliminar
Una vez detectado un comportamiento inusual en la mascota, ya sea por la cantidad de alimento ingerido, ritmo cardíaco o temperatura, no se enviaran se ´ nales ˜ de control como se había propuesto inicialmente sino se notificara que los datos tomados se encuentran ´ fuera de normalidad. Por ejemplo, si se ha ingerido mayor cantidad de alimento de lo estandarizado, no
se disminuira autom ´ | aticamente la raci ´ | on de alimento, ´
sino se dejara al usuario la realizaci ´ | on de esta tarea, ´
en base a los datos que la aplicacion proporciona. ´
La conexion entre la Raspberry Pi y el juguete se ´
realizara por medio de un m ´ | odulo bluetooth HC05 ´
en reemplazo a un modulo wi-fi, al ser una conexi ´ | on´
sencilla e igualmente efectiva.
2. Reducir
Con el objetivo de realizar una menor cantidad de
pruebas y calibracion de los elementos de medici ´ | on, se ´
enfocara la adquisici ´ | on de datos en caninos ´ | unicamente. ´
Por consiguiente, tambien se reducir ´ | a la base de datos ´
proporcionada a l usuaria y la comparacion de los mismos ´ realizados en la Raspberry Pi.
3. Incrementar
Inicialmente se había tenido en cuenta la cantidad nece-saria de alimentos que debe ingerir la mascota basados

PRIMERA ENTREGA PROYECTO, SISTEMAS EMBEBIDOS, BOGOTA D.C., COLOMBIA, 2 DE FEBRERO DE 2020 | 5 ´

unicamente en su peso; sin embargo, gracias a los datos ´
proporcionados por la PETMD es posible realizar una
clasificacion en funci ´ | on de la activar diaria que este tenga. ´
4. Crear
Se propone/realiza la creacion de prototipos en 3D para ´
obtener una mayor estetica en la presentaci ´ | on del pro- ´
yecto. Y la visualizacion de todos los datos obtenidos ´ y la interaccion con los dispositivos por medio de un ´ apliacion. ´

XI. COMPROMISO
Todos los integrantes del grupo se comprometen a realizar cada una de las actividades asignadas, enumeradas en la
seccion de ´ | Def inicion de tareas ´ | , para el día 5 de febrero
del 2020.

REFERENCIAS

[1] F. | Cantillo,.Este | monitor | de | actividad | no | es | para | ti, | es
para | tu | mascota”, | Nobbot, | 2019. | [Online]. | Available:
https://www.nobbot.com/tecnologia/dispositivos-tecnologicos-para-mascotas/.
[2] O. M. Radostits, I. G. Joe Mayhew, D. M. Houston, .

Examen y diagnostico
clínico en veterinaria”. Primera edicion, Madrid, Espa ´ | na. Ediciones ˜
Harcourt, 2002.
[3] PetMD, J. Cuotes, .

Are You Feeding Your Dog the Right Amount?” [Online]. Available: https://www.petmd.com/blogs/nutritionnuggets/dr-coates/2015/july/are-you-feeding-your-dog-right-amount-32905

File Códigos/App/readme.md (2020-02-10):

Debido a que la app es muy pesada se subio al siguiente drive https://drive.google.com/drive/folders/1IZmCD7Xg_HNJScJ4bdFQ6FJvwagL8eO6?usp=sharing

La segunda versión de la app puede ser consultada en https://drive.google.com/file/d/12nriZVxb5B5VfUwVT3Ob78sxEkaIbDEE/view?usp=sharing

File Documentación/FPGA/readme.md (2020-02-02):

## Primeros pasos FPGA BlackIceMx

Esta guía provee los recursos basicos necesarios para el uso de la FPGA desde Ubuntu.

### Instalación prerrequisitos

 Para el uso del dispositivo es necesario instalar Yosys tool chain. Pero primero se hace necesario instalar los prequisitor para compilar e instalar el icestorm, Arachne-PNR y Yosys tool chain 

	sudo apt-get install build-essential clang bison flex libreadline-dev gawk tcl-dev libffi-dev git mercurial graphviz xdot pkg-config python python3 libftdi-dev qt5-default python3-dev libboost-all-dev cmake libeigen3-dev

### Instalación herramientas

* Descarga e instalación IceStorm 

En un directorio vacío:

 	git clone https://github.com/cliffordwolf/icestorm.git icestorm
	cd icestorm
	make -j8
	sudo make install
					
* Descarga e instalación de Arachne-pnr
				
En el mismo directorio:

	git clone https://github.com/cseed/arachne-pnr.git arachne-pnr
	cd arachne-pnr
	make -j8
	sudo make install
					
* Instalción opcional NextPNR(reemplazo Arachne-PNR)

Desde el mismo directorio 

	git clone https://github.com/YosysHQ/nextpnr nextpnr
	cd nextpnr
	cmake -DARCH=ice40 -DCMAKE_INSTALL_PREFIX=/usr/local .
	make -j$(nproc)
	sudo make install

* Instalación Yosys 

En el mismo directorio 

	git clone https://github.com/cliffordwolf/yosys.git yosys
	cd yosys
	make -j8
	sudo make install

### Primer diseño

Para el primer programa usaremos un ejemplo prediseñado para la FPGA, por lo tanto, clonamos este ejemplo desde github, lo que se puede hacer con:

	git clone https://github.com/folknology/IceCore.git

Después de copiar el contenido

	cd IceCore/Examples/blink

En esta carpeta estará el archivo de pines(ucf), la descripción en verilog(chip.v y blink.v) y el archivo makefile, que permite sintetizar el codigo a un archivo bitstream en chip.bin. Para la sintentización usamos el comando: 

	make

### Cargando el primer diseño 

En el terminal se ejecutan los comandos:

	sudo bash
	usermod -a -G tty yourUserName
	usermod -a -G dialout yourUserName
	stty -F /dev/ttyACM0 raw -echo
	cat /dev/ttyACM0

Esto se hace para dar permisos al puerto y usuario. Después de esto, abrimos un nuevo terminal y ponemos:

	cat chip.bin >/dev/ttyACM0 

con lo que se cargará el programa

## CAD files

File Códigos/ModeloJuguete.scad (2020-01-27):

 
 difference(){  
difference()  {sphere(6,$fn=100); translate([0,-6,0])cube(12, center=true);}
sphere(5.8, $fn=100);
 
 }

 //difference(){
 //difference()  {sphere(4.92); translate([0,-4.5,0])cube(10, center=true);}
 //sphere(4.7);
 //}
 
 difference(){
 translate([0,5.6,0])
 rotate([90,90,0])

cylinder(r=1.45, h=2,$fn=100);
translate([0,6,0])
 rotate([90,90,0]){
cylinder(r=1.25, h=5,$fn=100);}
 
}

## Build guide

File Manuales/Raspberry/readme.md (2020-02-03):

## Inicio y pasos iniciales con la Raspberry Pi

En este documento se presentan los pasos y recursos iniciales para iniciar con la Raspberry Pi.

### Para iniciar todo:

* Descargar el archivo .img del sistema operativo (Raspbian Lite) desde https://www.raspberrypi.org/downloads/raspbian/, la guía de instalación se encuentra en https://www.raspberrypi.org/documentation/installation/installing-images/linux.md
* Correr el comando 

	lsblk

para saber donde está ubicada la memoria SD donde se va a instalar el .img (será algo como /dev/sdX, donde X es una letra).
* Correr el siguiente comando teniendo mucho cuidado de elegir bien el disco: sudo dd if=nombreIMG of=/ubicaciónDisco bs=8M
	
Ejemplo:

	sudo dd bs=8M if=2019-07-10-raspbian-buster-lite.img of=/dev/sdb status=progress conv=fsync
	
* Cuando haya finalizado la instalación, ir a la carpeta boot y modificar:
	- config.txt: agregar enable_uart=1 al final
	- cmdline.txt: se elimina la palabra “quiet”

Crear un archivo vacio con el nombre "ssh" en la carpeta raiz, usar el comando:
	
	sudo echo "" > ssh
	
* Insertar la microSD en la RPI y conectar con cable ethernet al PC

* Si se desea ingresar por puerto serial, correr:
	- Para configurar minicom: sudo minicom -s, configuración de la puerta serial, elegir bien donde está conectado el conversor ttl (ttyUSB0 generalmente) y que la velocidad sea 115200.
	- Para conectarse: minicom.
* Para conectarse con ethernet, correr sudo nm-connection-editor, ir a conexión cableada, ajustes de ipv4 y habilitar compartir con otros equipos.
* Con la raspberry conectada por ethernet correr en el computador:

Para conocer la dirección del PC:

	ifconfig
	
La primera dirección que aparece es la del PC, por ejemplo 10.42.0.1. Para buscar la dirección asignada a la RasPi:

	nmap -sT 10.42.0.2-254 

Los primeros 3 números son los primeros 3 de la dirección IP del PC, por ejemplo 10.42.0.29. Para conectarse a la Raspberry:

	ssh pi@10.42.0.29
	contraseña: raspberry

Finalmente, para actualizar paquetes: 
	
	sudo apt update
	sudo apt upgrade

### Para instalar los servidores:

* Servidor de paginas web:

Instalar con: 
	
	sudo apt install apache2

Se puede verificar la instalación ingresando la dirección ip en un navegador. Las páginas se encuentran en la ubicación var/www/html. Se puede eliminar la página por defecto con:
	
	sudo mv index.html index.old
	
Para escribir una nueva: 
	
	sudo nano index.html

* Servidor de bases de datos:

Instalar con:
	
	sudo apt install mariadb-client mariadb-server
	
Para entrar a la base de datos desde bash:

	sudo mysql -u root -p
	
Para instalar phpmyadmin, el manejador html de base de datos que combina servidor de paginas y de base de datos (conexión de capa baja entre base y páginas): 
		
	sudo apt install phpmyadmin
		
En la dirección IP_rasp/phpmyadmin se encuentra la página web para manejar las bases de datos desde un navegador. Si no se encuentra, intentar (https://askubuntu.com/questions/387062/how-to-solve-the-phpmyadmin-not-found-issue-after-upgrading-php-and-apache): 

Abrir el archivo de configuración con:

	sudo nano /etc/apache2/apache2.conf
			
Agregar al final del archivo y guardar: 

	Include /etc/phpmyadmin/apache.conf

Reiniciar apache con: 

	/etc/init.d/apache2 restart
			
- Para poder acceder, seguir (https://stackoverflow.com/questions/5908752/can-anyone-confirm-that-phpmyadmin-allownopassword-works-with-mysql-databases y https://www.iven.in/2016/11/solved-phpmyadmin-1698-access-denied.html):

Para ir al archivo de configuración de phpmyadmin:

	sudo nano /etc/phpmyadmin/config.inc.php 

Buscar la siguiente línea, descomentarla y guardar el archivo:

	$cfg['Servers'][$i]['AllowNoPassword'] = TRUE; 
 Luego:
	
	sudo mysql -u root
	use mysql;
	update user set plugin='' where User='root';
	flush privileges;
	\q

### Configuración del access point:

* Seguir el tutorial: https://www.raspberrypi.org/documentation/configuration/wireless/access-point.md
	- NOTA: evitar agregar denyinterfaces eth0, vuelve la raspberry indetectable con ethernet.
Para reiniciar:

	sudo service dhcpcd restart
	sudo service hostapd restart
	sudo systemctl reload dnsmasq

Para verificar si está funcionando:

	sudo service hostapd status
	sudo service dnsmasq status
	sudo systemctl status dnsmasq
	sudo systemctl status hostapd
	
Para verificar el estado del punto de acceso: 

	sudo tail -f /var/log/syslog

Si el tutorial no funciona, instalar create_ap:
	- Leer README en https://github.com/oblique/create_ap
	- Luego correr:
	
	git clone https://github.com/oblique/create_ap
	cd create_ap
	make install
	
- El archivo de configuración está en la ubicación: /etc/create_ap.conf

El punto de acceso se inicia con: 

	sudo create_ap --config /etc/create_ap.conf

Para que se inicie en boot usar systemd: 

	sudo systemctl start create_ap
	sudo systemctl enable create_ap

### Instalación de node-RED:

- Seguir https://nodered.org/docs/getting-started/raspberrypi:

Script para instalación y actualización: 

	bash <(curl -sL https://raw.githubusercontent.com/node-red/linux-installers/master/deb/update-nodejs-and-nodered) 

Instalar mosquitto-mqtt (protocolo de mensajeria usando un modelo de publicación/susbcripción: https://mosquitto.org/) con:

	sudo apt install mosquitto

### Comandos utiles:

Permite ver algunas líneas de algún archivo log (reemplazar logFILE): 
	
	sudo tail -f /var/log/logFILE
	
Uso del disco en tamaños de bloque: 

	df -k
	
Uso del disco en múltiplos de 1024: 

	df -h
	
En el PC permite ver si hay conexión por ssh con la Raspberryv (reemplazar ip_rasp): 

	ping ip_rasp 

En la Raspberry permite ver si hay conexión por ssh con el pc (reemplazar ip_rasp): 
	
	ping ip_pc

En el PC, ver donde está montado el disco de la Raspberry: 

	lsblk

Para hacer una copia de seguridad del disco de la raspberry en el pc: 
	
	sudo dd bs=8M if=/dev/sdX of=backup_rpi.img status=progress conv=fsync count=used/8000
	
- X es la letra donde esté montada la memoria, ver lsblk
- used/8000 es para que dd no copie toda la memoria, used será la cantidad de disco usada por la raspberry (ver df -k), aproximar la división hacia arriba.

Configuraciones varias de la raspberry

	sudo raspi-config
	
Para buscar todos los archivos bajo algún nombre (reemplazar quest): 

	sudo find | grep quest

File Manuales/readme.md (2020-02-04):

**Nota:** Estos manuales están basados en la beta de la aplicación EMPET a fecha de 3 de febrero de 2020.

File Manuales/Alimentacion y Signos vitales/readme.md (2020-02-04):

## Alimentación

1.	Llene los tazones para la comida y el agua en el comedero EMPET según lo marcado en este.
2.	 Ingrese a la aplicación EMPET en su dispositivo móvil, en esta acceda al menú principal y presione sobre el botón de alimentación.
3.	En la página en la que acaba de ingresar se presenta el peso de la comida y agua que tiene el perro en sus tazones en gramos.

**Nota:** La cantidad de comida y agua se actualiza cada 10 segundos.

## Signos vitales

1.	Ubique el dispositivo de medición EMPET en la parte interior de la ingle del perro en una región con muy poco pelo y lo más cercano posible a las venas y arterias superficiales.
2.	Ingrese a la aplicación EMPET en su dispositivo móvil, en esta acceda al menú principal y presione sobre el botón de signos vitales.
3.	En la página en la que acaba de ingresar se presenta la cantidad de latidos por minuto del perro y su temperatura corporal.

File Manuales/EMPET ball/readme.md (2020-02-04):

## EMPET Ball

<p align="center">
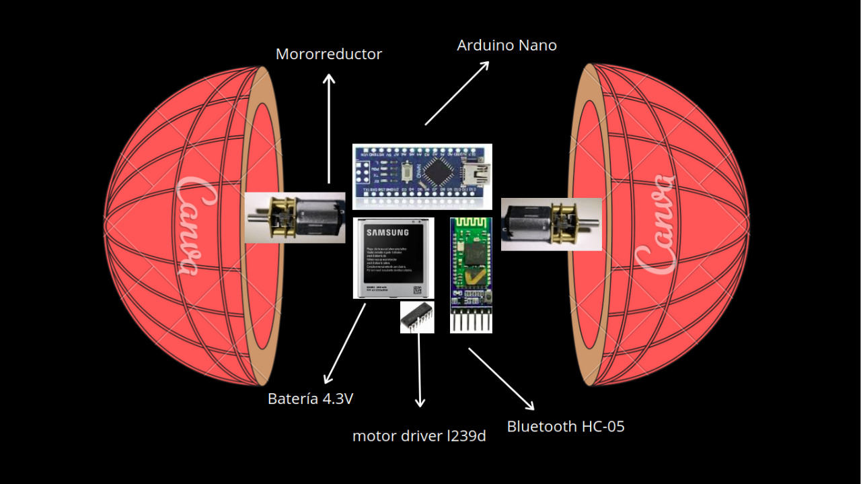
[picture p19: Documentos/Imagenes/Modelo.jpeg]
  
</p>

Para hacer uso del dispositvo ingrese a la aplicación EMPET. Haga click en el botón de jugar, ubicado en el menú principal, donde se desplegarán dos opciones, autómatico y manual.

## Modo Automático
Este modo permitirá al usuario mover aleatoriamente la pelota. La comunicación se realiza mediante el servidor, por lo cuál 
podrá acceder al dispositivo estando fuera de la casa. Simplemente se debe presionar el boton "activar" para encender el dispositivo y "desactivar" para detenerlo.

## Modo Manual

Este modo despliega una página que contiene opciones para mover el dispositivo en cuatro direcciones (Adelante, atrás, izquierda, derecha) mediante el 
control que se muestra en pantalla. La comunicación se realiza vía bluetooth, por lo cual se podrá acceder a este modo 
por una distancia restringida.

El primer paso es conectar el dispositivo a bluetooth, para ello hay que hacer click en 'Refresh Bluetooth Devices', luego en 
'Connect Bluetooth Devices", seleccionar el dispositivo cuyo nombre es 'OMSP' e inmediatamente debe salir una notificación 
'Connect Successful'.

<p align="center">
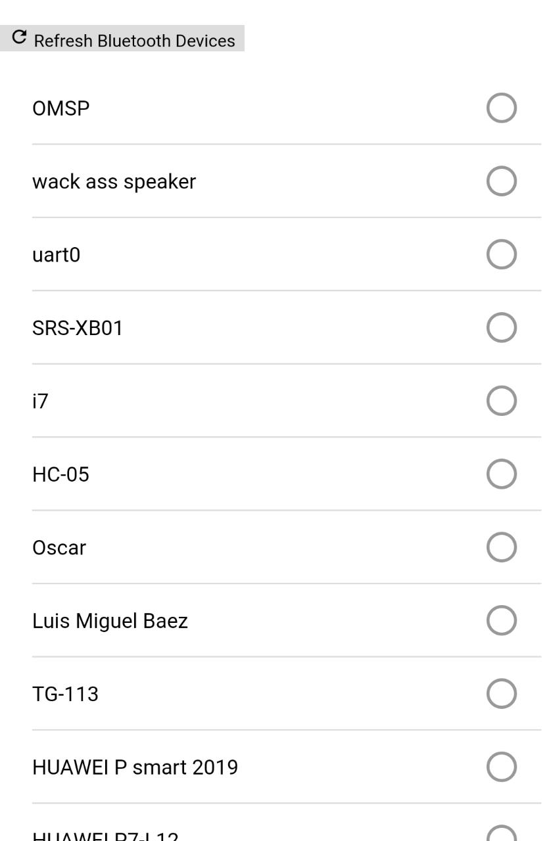
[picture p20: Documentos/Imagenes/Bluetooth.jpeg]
  
</p>

El paso dos consiste en controlar el disposito con ayuda de los botones que salen en la pantalla.

<p align="center">
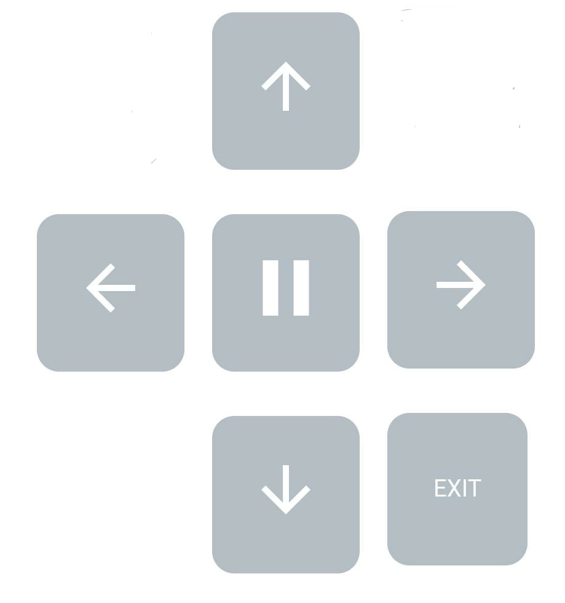
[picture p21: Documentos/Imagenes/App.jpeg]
  
</p>
Finalmente, para salir del modo manual, el usuario debe presionar el boton "exit".

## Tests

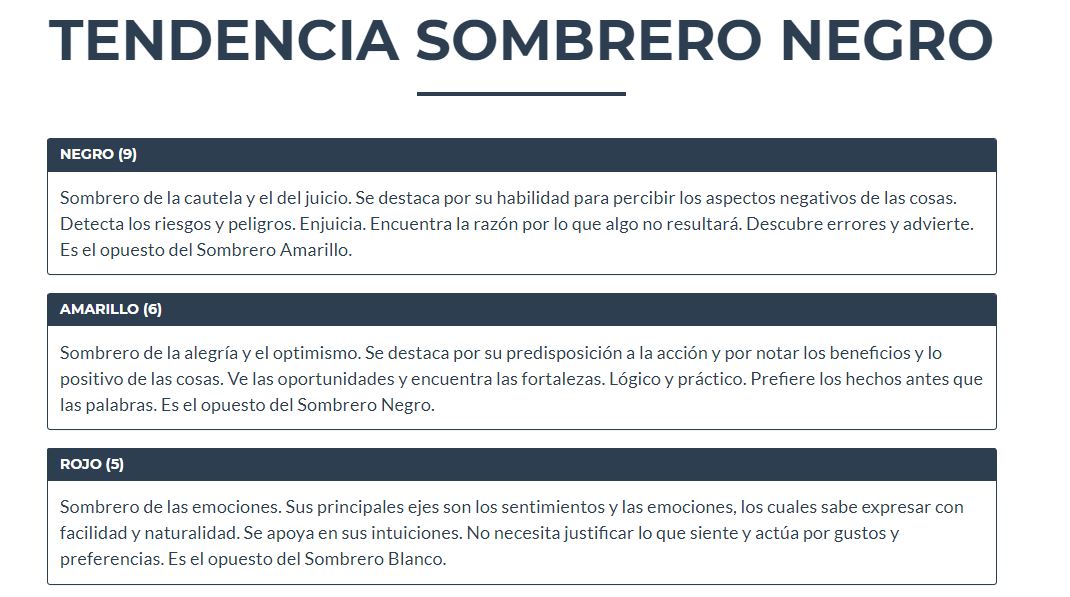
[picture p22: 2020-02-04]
Documentos/Test de los 6 sombreros/sombrerosOscar.JPG

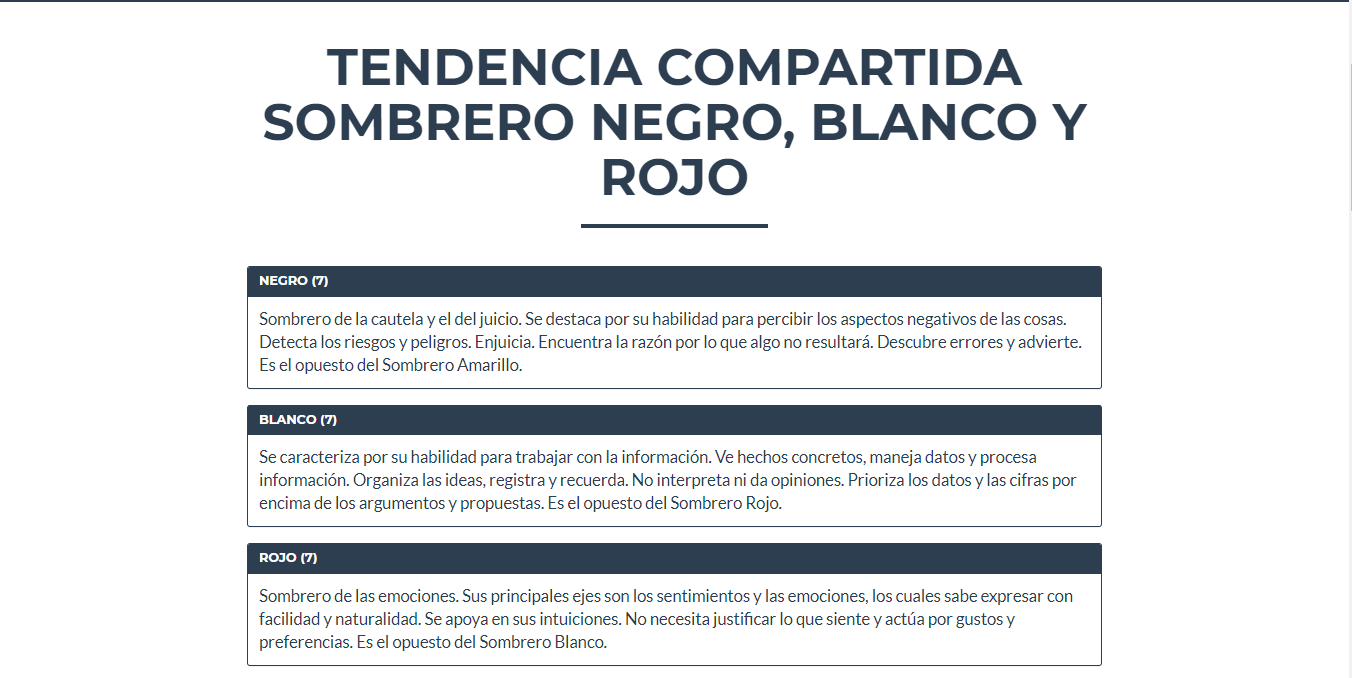
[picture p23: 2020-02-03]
Documentos/Test de los 6 sombreros/sombrerosJulian.png

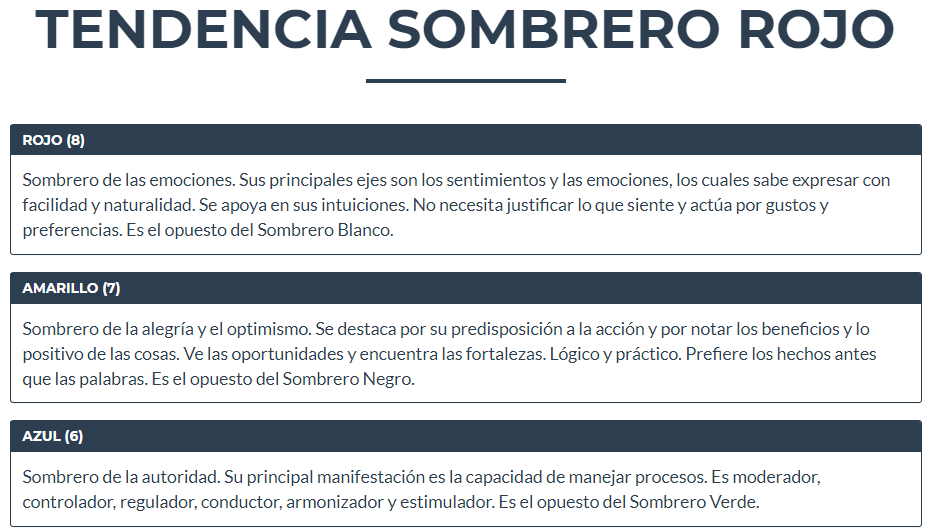
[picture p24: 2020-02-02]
Documentos/Test de los 6 sombreros/sombrerosPedro.PNG

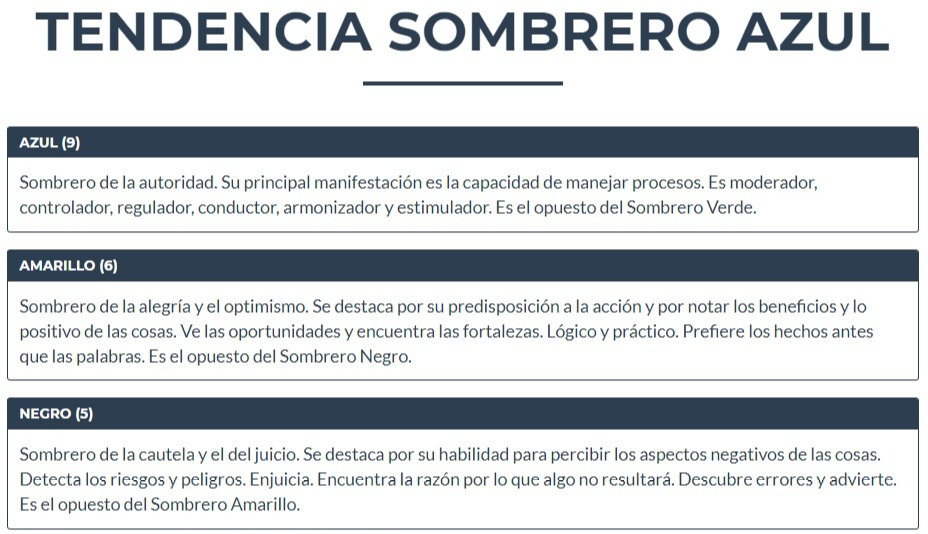
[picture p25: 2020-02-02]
Documentos/Test de los 6 sombreros/sombrerosMaria.PNG

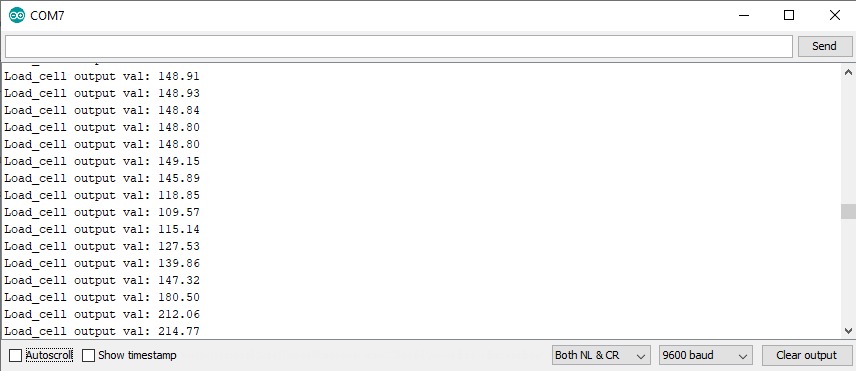
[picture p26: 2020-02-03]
Documentación/Sensores/HX711 y celda de carga/CeldaCalibrada.jpeg

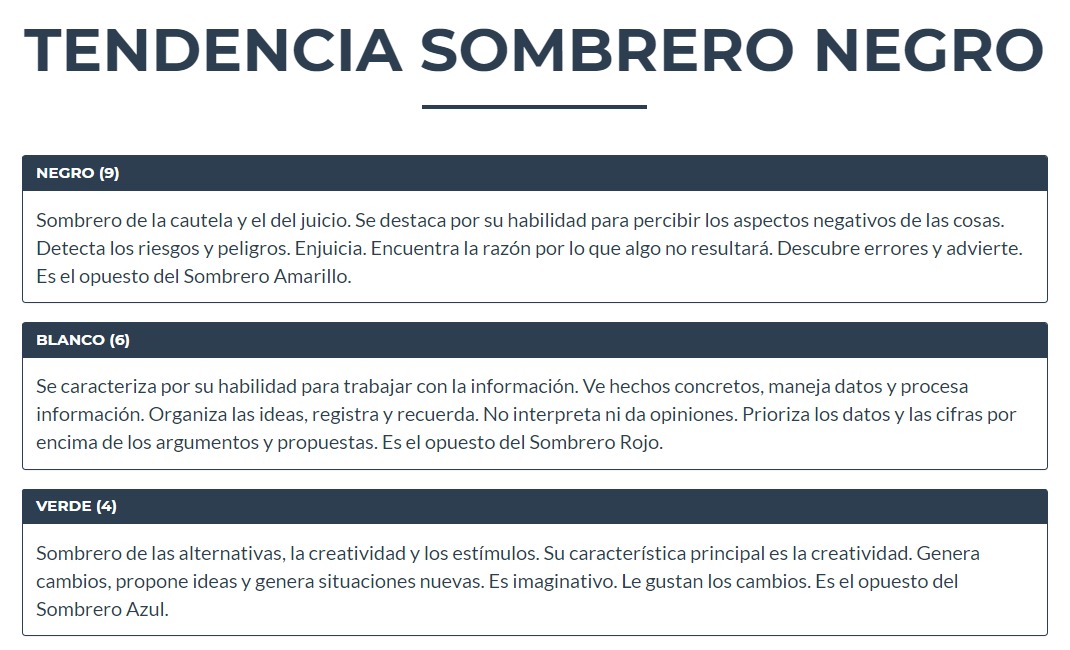
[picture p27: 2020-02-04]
Documentos/Test de los 6 sombreros/sombrerosCamilo.jpeg

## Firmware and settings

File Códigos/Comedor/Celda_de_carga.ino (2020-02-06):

//-------------------------------------------------------------------------------------
// HX711_ADC.h
// Arduino master library for HX711 24-Bit Analog-to-Digital Converter for Weigh Scales
// Olav Kallhovd sept2017
// Tested with      : HX711 asian module on channel A and YZC-133 3kg load cell
// Tested with MCU  : Arduino Nano, ESP8266
//-------------------------------------------------------------------------------------
// This is an example sketch on how to use this library
// Settling time (number of samples) and data filtering can be adjusted in the config.h file

// This example shows how to calibrate the load cell and optionally save the calibration  
// value to EEPROM, and also how to change the value.
// The value can later be fetched from EEPROM in your project sketch.

#include <HX711_ADC.h>
#include <EEPROM.h>

//HX711 constructor (dout pin, sck pin):
HX711_ADC LoadCell(4, 5);

int eepromAdress = 0;

long t;

void calibrate() {
  Serial.println("***");
  Serial.println("Start calibration:");
  Serial.println("It is assumed that the mcu was started with no load applied to the load cell.");
  Serial.println("Now, place your known mass on the loadcell,");
  Serial.println("then send the weight of this mass (i.e. 100.0) from serial monitor.");
  float m = 0;
  boolean f = 0;
  while (f == 0) {
    LoadCell.update();
    if (Serial.available() > 0) {
      m = Serial.parseFloat();
      if (m != 0) {
        Serial.print("Known mass is: ");
        Serial.println(m);
        f = 1;
      }
      else {
        Serial.println("Invalid value");
      }
    }
  }
  float c = LoadCell.getData() / m;
  LoadCell.setCalFactor(c);
  Serial.print("Calculated calibration value is: ");
  Serial.print(c);
  Serial.println(", use this in your project sketch");
  f = 0;
  Serial.print("Save this value to EEPROM adress ");
  Serial.print(eepromAdress);
  Serial.println("? y/n");
  while (f == 0) {
    if (Serial.available() > 0) {
      char inByte = Serial.read();
      if (inByte == 'y') {
        #if defined(ESP8266) 
        EEPROM.begin(512);
        #endif
        EEPROM.put(eepromAdress, c);
        #if defined(ESP8266)
        EEPROM.commit();
        #endif
        EEPROM.get(eepromAdress, c);
        Serial.print("Value ");
        Serial.print(c);
        Serial.print(" saved to EEPROM address: ");
        Serial.println(eepromAdress);
        f = 1;

      }
      else if (inByte == 'n') {
        Serial.println("Value not saved to EEPROM");
        f = 1;
      }
    }
  }
  Serial.println("End calibration");
  Serial.println("For manual edit, send 'c' from serial monitor");
  Serial.println("***");
}

void changeSavedCalFactor() {
  float c = LoadCell.getCalFactor();
  boolean f = 0;
  Serial.println("***");
  Serial.print("Current value is: ");
  Serial.println(c);
  Serial.println("Now, send the new value from serial monitor, i.e. 696.0");
  while (f == 0) {
    if (Serial.available() > 0) {
      c = Serial.parseFloat();
      if (c != 0) {
        Serial.print("New calibration value is: ");
        Serial.println(c);
        LoadCell.setCalFactor(c);
        f = 1;
      }
      else {
        Serial.println("Invalid value, exit");
        return;
      }
    }
  }
  f = 0;
  Serial.print("Save this value to EEPROM adress ");
  Serial.print(eepromAdress);
  Serial.println("? y/n");
  while (f == 0) {
    if (Serial.available() > 0) {
      char inByte = Serial.read();
      if (inByte == 'y') {
        #if defined(ESP8266)
        EEPROM.begin(512);
        #endif
        EEPROM.put(eepromAdress, c);
        #if defined(ESP8266)
        EEPROM.commit();
        #endif
        EEPROM.get(eepromAdress, c);
        Serial.print("Value ");
        Serial.print(c);
        Serial.print(" saved to EEPROM address: ");
        Serial.println(eepromAdress);
        f = 1;
      }
      else if (inByte == 'n') {
        Serial.println("Value not saved to EEPROM");
        f = 1;
      }
    }
  }
  Serial.println("End change calibration value");
  Serial.println("***");
}

void setup() {
  Serial.begin(9600); delay(10);
  Serial.println();
  Serial.println("Starting...");
  LoadCell.begin();
  long stabilisingtime = 2000; // tare preciscion can be improved by adding a few seconds of stabilising time
  LoadCell.start(stabilisingtime);
  if (LoadCell.getTareTimeoutFlag()) {
    Serial.println("Tare timeout, check MCU>HX711 wiring and pin designations");
  }
  else {
    LoadCell.setCalFactor(1.0); // user set calibration value (float)
    Serial.println("Startup + tare is complete");
  }
  while (!LoadCell.update());
  calibrate();
}
void loop() {
  //update() should be called at least as often as HX711 sample rate; >10Hz@10SPS, >80Hz@80SPS
  //longer delay in sketch will reduce effective sample rate (be carefull with delay() in the loop)
  LoadCell.update();

  //get smoothed value from the data set
  if (millis() > t + 250) {
    float i = LoadCell.getData();
    Serial.print("Load_cell output val: ");
    Serial.println(i);
    t = millis();
  }

  //receive from serial terminal
  if (Serial.available() > 0) {
    float i;
    char inByte = Serial.read();
    if (inByte == 't') LoadCell.tareNoDelay();
    else if (inByte == 'c') changeSavedCalFactor();
  }

  //check if last tare operation is complete
  if (LoadCell.getTareStatus() == true) {
    Serial.println("Tare complete");
  }

}

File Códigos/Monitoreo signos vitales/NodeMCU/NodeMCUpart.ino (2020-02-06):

#define DEBUG_ARRAY(a) {for (int index = 0; index < sizeof(a) / sizeof(a[0]); index++)    {Serial.print(a[index]); Serial.print('\t');} Serial.println();};
#include<SoftwareSerial.h>
#include <ESP8266WiFi.h>
#include <PubSubClient.h>

SoftwareSerial SUART(D6, D5); //SRX=Dpin-D2; STX-DPin-D1

// Variables para la conexion WiFI
const char* ssid = "EmPetAP";
const char* password = "12345678";
const char* mqtt_server = "10.42.0.29";

WiFiClient espClient;
PubSubClient client(espClient);

//Variables para subir datos al servidor.
long lastMsg = 0;
int msg0;
int msg1;
char msg[50];
char char0[50];
char char1[50];
int value = 0;

//Variables recuperación datos.
int tempC;
int pulso;
String str;
const char separador = ',';
const int dataLong = 2;
int data[dataLong];

//--------------------------------------------

void setup()
{
  pinMode(BUILTIN_LED, OUTPUT);
  Serial.begin(115200); //enable Serial Monitor
  SUART.begin(115200); //enable SUART Port
  setup_wifi();
  client.setServer(mqtt_server, 1883);
  client.setCallback(callback);

}

void setup_wifi() {

  delay(10);
  // We start by connecting to a WiFi network
  Serial.println();
  Serial.print("Connecting to ");
  Serial.println(ssid);

  WiFi.begin(ssid, password);

  while (WiFi.status() != WL_CONNECTED) {
    delay(500);
    Serial.print(".");
  }

  Serial.println("");
  Serial.println("WiFi connected");
  Serial.println("IP address: ");
  Serial.println(WiFi.localIP());
}

void callback(char* topic, byte* payload, unsigned int length) {
  Serial.print("Message arrived [");
  Serial.print(topic);
  Serial.print("] ");
  for (int i = 0; i < length; i++) {
    Serial.print((char)payload[i]);
  }
  Serial.println();

  // Switch on the LED if an 1 was received as first character
  if ((char)payload[0] == '1') {
    digitalWrite(BUILTIN_LED, LOW);   // Turn the LED on (Note that LOW is the voltage level
    // but actually the LED is on; this is because
    // it is acive low on the ESP-01)
  } else {
    digitalWrite(BUILTIN_LED, HIGH);  // Turn the LED off by making the voltage HIGH
  }

}

void reconnect() {
  // Loop until we're reconnected
  while (!client.connected()) {
    Serial.print("Attempting MQTT connection...");
    // Attempt to connect
    if (client.connect("ESP8266Client")) {
      Serial.println("connected");
      // Once connected, publish an announcement...
      client.publish("/sensor/temp", "Enviando");
      // ... and resubscribe
      client.subscribe("/test/test2");
    } else {
      Serial.print("failed, rc=");
      Serial.print(client.state());
      Serial.println(" try again in 5 seconds");
      // Wait 5 seconds before retrying
      delay(5000);
    }
  }
}

void loop()
{

  if (!client.connected()) {
    reconnect();
  }
  client.loop();

  long now = millis();
    
  byte n = SUART.available(); //n != 0 means a character has arrived
  if (n != 0)
  {
   if (SUART.available())
   {
      str = SUART.readStringUntil('\n');
      for (int i = 0; i < dataLong ; i++)
      {
         int index = str.indexOf(separador);
         data[i] = str.substring(0, index).toInt();
         str = str.substring(index + 1);
      }
      DEBUG_ARRAY(data);
  }
  }
  msg0=data[0];
  msg1=data[1];
  
  //msg0.toCharArray(char0, 50)
  //msg1.toCharArray(char1,50)
  if (now - lastMsg > 1000) {
    lastMsg = now;
    //++value;
    itoa(msg0, char0, 10);
    itoa(msg0, char0, 10);
    Serial.print("Publish message: ");
    Serial.print(msg0);
    Serial.print("      ");
    Serial.print(msg1);
    client.publish("/sensor/temp", char0);
    client.publish("/sensor/pulso", char1);
  }


}

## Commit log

2020-01-27 Add files via upload
    Modelo para impresión 3D del juguete, realizado en el software OpenScad.
    [ModeloJuguete.scad]
2020-02-03 Rename Manuales/Sensores/HX711 y celda de carga/readme.md to Documentación/Sensores/HX711 y celda de carga/readme.md
2020-02-03 Rename Manuales/Sensores/Pulse Sensor/readme.md to Documentación/Sensores/Pulse Sensor/readme.md
2020-02-04 Rename Documentación/Modulos de comunicación/NodeMCU/readme.md to Documentación/Comunicacion/NodeMCU/readme.md
2020-02-04 Create actuadores y motorreductor.md
2020-02-04 Rename readme.md to actuadores y motorreductor.md
2020-02-04 Rename Documentación/Comunicación/Actuadores y Motorreductor/actuadores y motorreductor.md to Documentación/Comunicación/Actuadores y Motorreductoractuadores y motorreductor.md
2020-02-04 Rename Documentación/Comunicación/Actuadores y Motorreductoractuadores y motorreductor.md to Documentación/Actuadores y Motorreductor/actuadores y motorreductor.md
2020-02-04 Rename actuadores y motorreductor.md to readme.md
2020-02-06 Create SensoresArduino
2020-02-06 Rename Códigos/Envio de pulso y temperatura a base de datos/readme.md to Códigos/NodeMCU/readme.md
2020-02-06 Rename Códigos/Envio de pulso y temperatura a base de datos/Arduinopart.ino to Códigos/SensoresArduino/Arduinopart.ino
2020-02-06 Rename Códigos/SensoresArduino/Arduinopart.ino to Códigos/Monitoreo signos vitales/SensoresArduino/Arduinopart.ino
